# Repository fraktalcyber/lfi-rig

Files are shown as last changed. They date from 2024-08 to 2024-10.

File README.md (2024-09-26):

# Fraktal - Laser Fault Injection (LFI) rig

This project is Fraktal's take on building an affordable Laser Fault Injection rig that allows anyone to get started with performing laser fault injection attacks, previously left only for laboratories and research institutes with expensive equipment. With this breakthrough, we hope to inspire a new wave of research and development in hardware security.

The series of blog posts related to this repository can be read from our blog
[Part 1](https://blog.fraktal.fi/laser-fault-injection-for-the-masses-1860afde5a26),
[Part 2](https://medium.com/fraktal/laser-fault-injection-for-the-masses-part-2-b86a42fd28a1), 
[Part 3](https://medium.com/fraktal/laser-fault-injection-for-the-masses-part-3-86372a233db9)

## Contents of the repository

- **Decapping** - Instructions, guidance and methodologies for decapping chips
- **LFI** - Instructions, guidance and methodologies for Laser Fault Injection and how to get the best out of the rig
- **Other** - Various other things and source material we have created and come across
- **PCB** - KiCAD project, schematic and board files for the XY2-100 driver board
- **rigv2** - 2nd generation rig using off-the-shelf xTool F1 laser engraver
- **src** - Micropython script including the XY2-100 software driver and control for the laser PWM, beam pattern visualizer

## UPDATE
Rigv2 using off-the-shelf xTool F1 laser engraver. A bit more money but a lot less hassle. Read the details from [rigv2](/rigv2/README.md)

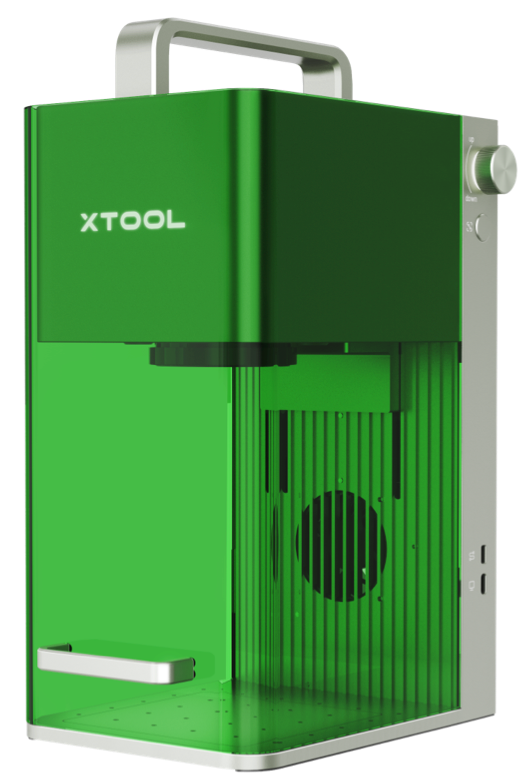
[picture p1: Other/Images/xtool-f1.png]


## Chip Decapping
**The rig is capable of decapping chips!** This capability drastically simplifies the decapping process, as you can decap and then immediately move on to glitching the chip — no need to switch between different equipment or complicated setups. Read more from [decapping](https://github.com/fraktalcyber/lfi-rig/blob/main/Decapping/README.md)

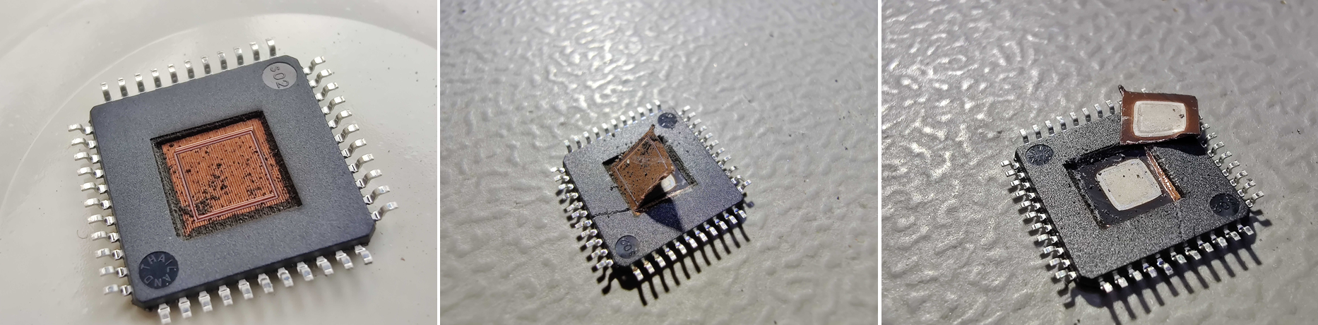
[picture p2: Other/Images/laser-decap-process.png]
Laser Decap


## WARNING

**Before attempting to build and use this rig, please be aware that the 1064nm IR laser is invisible to the eye and extremely dangerous. As the rig is running high powered lasers even a reflected beam can cause immediate severe eye damage.** 

It is imperative to wear laser safety goggles that filter out 1064nm light and to operate the rig in a secure, enclosed box. Line the box with aluminum foil or similar materials to ensure the IR light cannot penetrate. Safety should always be your top priority as any damage to your sight is likely going to be permanent. Also be aware of the potential fire hazards as a powerful IR laser will easily burn through even thin metal.

When buying goggles, get them from reputable sources that provide some certification or other documentation so you can be sure the glasses actually filter the wavelengths. [Example from Farnell](https://fi.farnell.com/imatronic/1900-08-000/laser-safety-glasses-870-1085nm/dp/2334333)

**If you decide to decap chips with the rig here are some additional warnings.**

Ensure you have adequate fume extraction as the fumes emitted from the burning epoxy, fillers and additives in the coating can be very toxic to inhale. We are performing this in a sealed enclosure with Weller fume extractor that has active carbon filter. 

Fire hazards, as you are giving laser treatment for the epoxy, even though it has flame retardants, there is still a risk of combustion. Never leave the rig without supervision when doing this and have fire extinguisher at hand just in case.

## Shopping list

This details the main components needed to build the rig. The bill of materials for the XY2-100 driver board is listed in the README.md under the PCB folder.

- **Galvanometer (Galvo scanner):** Any that uses XY2–100 protocol and has 1064nm IR coating on the mirrors will do.  These can be had from AliExpress from various sellers for around 130 €, prices seem to vary wildly between sellers and days. If it has a DB-25 connector it likely works with our driver board directly
- **1064nm F-Theta lens:** The smaller the scan area / focus length, the higher the precision. Around 50 €.
- **1064nm IR Laser light source:** Any with at least 200 mW of optical power. The more powerful laser you have the faster you can run the rig. We started with a 200mW module which we were able to haggle to around 50 € from Alibaba but eventually settled for an off-the-shelf Sculpfun IR-2, 2W IR laser module which has integrated driver and enough power to run the rig as fast as the mirrors can move. We managed to get the IR-2 module from a campaign in Alibaba for 220 €. IR-2 is also nice because it has a red alignment laser which makes it possible to see where the laser is pointing.
- **Raspberry Pi Pico:** 5 €.
- **4 channel RS-422/485 driver:** To drive X, Y, Sync and CLK channels in XY2–100 protocol. We used Analog Devices LTC487CSW, 10 € .
- **Power supply:** Capable of providing +-15V @ 2A, we initially used a multi-channel bench power supply. For the final version we used embedded Tracopower TEN60–2423N supply which is 97 € but makes it possible to have everything in a single PCB.

## Assembly and setup

After obtaining all of the required items from the shopping list (and optionally built the driver board all you have left is to assemble the thing. If you went with the Sculpfun IR-2 laser this step is pretty straight forward.

### Mounting the laser to the Galvanometer

Mount the laser to the hole in the galvanometer. You can build proper brackets or just duct tape it together like we have. Both work equally well. Whatever you do, leave things a bit loose for now so that it is possible to align the beam to the center of the hole when you power the rig on.

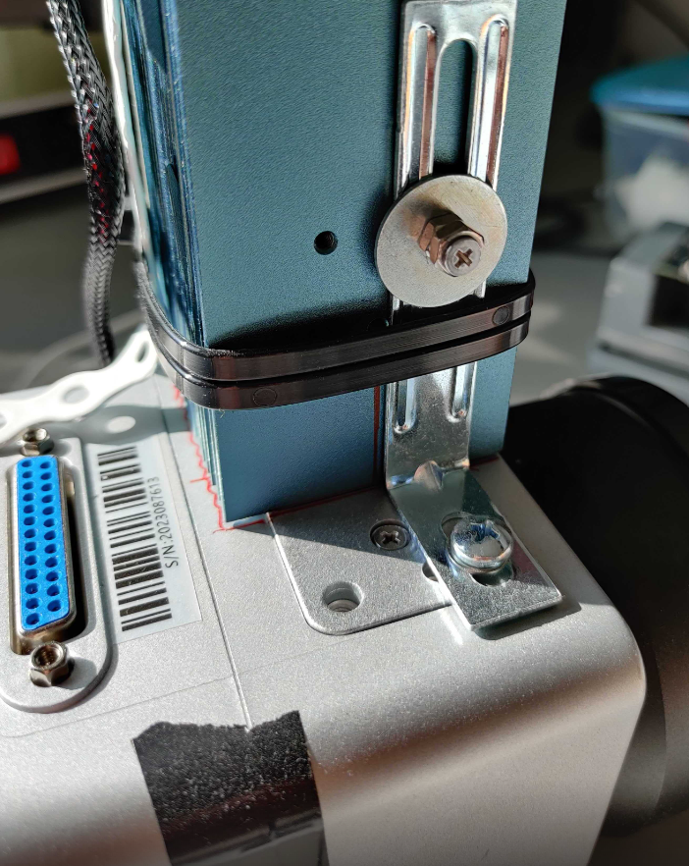
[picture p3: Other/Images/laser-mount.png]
Laser Mount


### Attaching the lens

Screw in the F-Theta lens. Before attaching the lens, make sure the mirrors and the lens are clean and don't have any dust particles or other dirt as that will be likely burnt to the mirror surface when you first time power on the laser.

### Holding the rig in place

We are holding the rig in place in our lab simply with a monitor mount that can be height adjusted and which has VESA mount that can be tilted 90 degrees. The VESA mount has two L-Brackets attached to it that hold the rig in place.

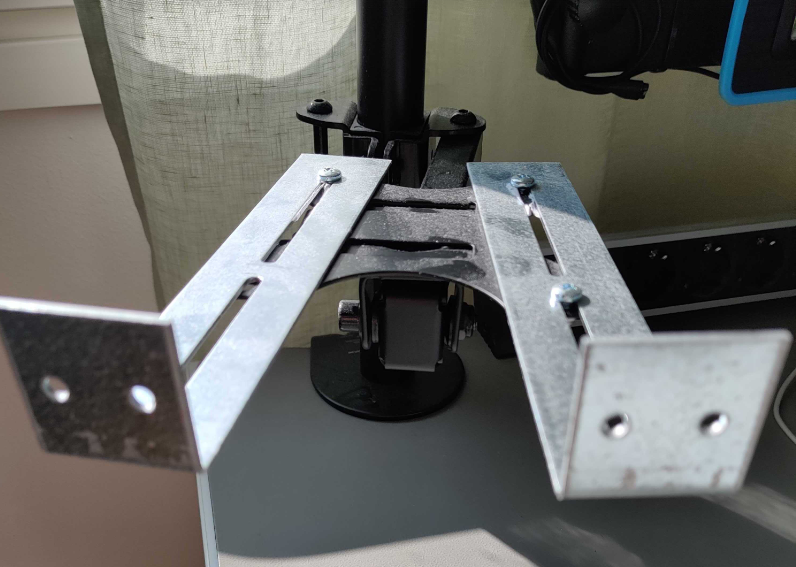
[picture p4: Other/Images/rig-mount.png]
Rig Mount


### Assembling the driver PCB

The driver PCB has very few parts and is pretty straight forward to assemble. There are only few things that should be considered.

- Although the Raspberry Pi Pico can be mounted flush on the PCB we suggest mounting a pin header to the holes and then pressing the Pico in. This has benefits, it leaves a bit more clearance under the Pico and fits even the bulkiest Micro USB cables, it allows to use the pads to mount wires and additional headers for monitoring etc. We are for example driving the target chip power often straight from the Pico as this makes wiring a bit simpler. For this we have added few extra headers for select pins.
- **DB-15 Header should be mounted to the backside of the PCB**, with the rest of the components on the frontside where the Raspberry Pi Pico is.
- The PCB BOM is listed with more detail underneath the PCB folder

### Connecting all the cables and wiring pinouts

Most of the available galvanometers seem to be using similar structure and come with DB-25 connector in the galvanometer itself. It is still worth to check that the one you are planning on buying has same or similar pinout to what we used if you are planning on running our driver board.

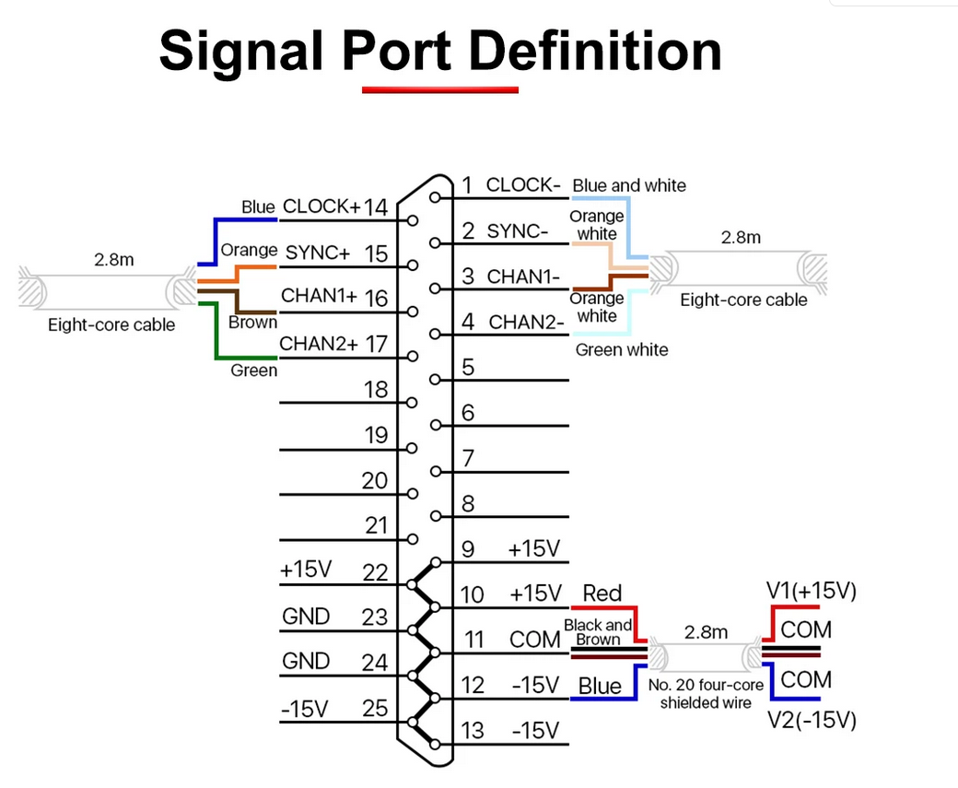
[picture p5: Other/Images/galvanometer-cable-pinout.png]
Galvo Pinout


These galvanometers come with wiring harness that has DB-25 that goes to the galvanometer with the other end having DB-15 and four loose cables. The DB-15 connector is used for the XY2-100 four channels and you can verify the pinout by beeping the cable with a multimeter in continuity mode. DB-15 should work directly with our driver and can be connected straight to the PCB.

*As we didn't want to run the rig from mains with insufficient protections, We ditched the power supply that came with the galvanometer as that connects straight to mains and doesn't offer same amount of protections as a lab power supply can provide.*

The four loose cables we had in our harness were coloured blue (-15VDC), black (GND), red (+15VDC) and yellow (Mains Earth **DO NOT CONNECT THIS UNLESS YOU KNOW WHAT YOU ARE DOING**). Blue, black and red wires can be connected to the Galvo OUT header on the driver PCB.

If you are running the Sculpfun IR-2 laser, the laser probably came with this type of connector.

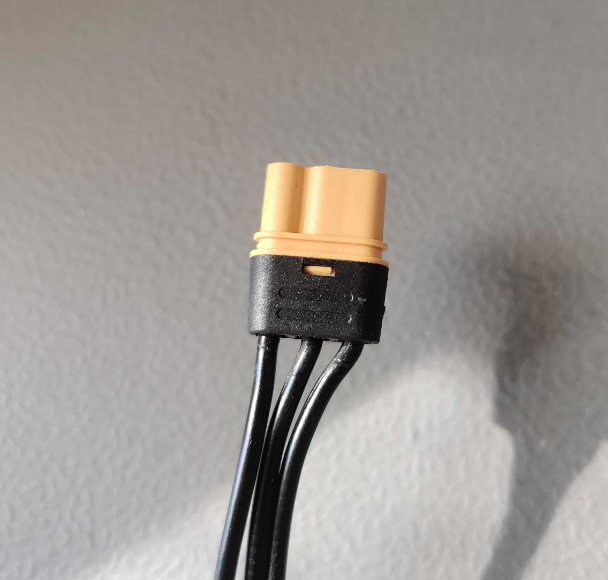
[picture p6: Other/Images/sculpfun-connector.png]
Sculpfun Pinout


The pinout for the connector is from left to right, 1kHZ PWM signal @ 3V3, GND, +24VDC

When connecting the PWM signal to the respective header on the driver PCB, it is **highly recommended to add a mechanical switch on the signal wire** this allows you to have a mechanical safety switch and prevent accidental running of the laser main beam. Only toggle the switch when everything is enclosed and you are wearing your goggles.

With everything connected it is time for test run!

### Testing the rig works and aligning the laser

With everything connected and setup the first thing you should do is to align the laser. If you went with Sculpfun IR-2, you can power the laser **with PWM signal disconnected**. This should give you a red laser spot that is the alignment beam that is firing **when the main beam is not firing**. The alignment beam spotsize is much larger than the actual IR laser spot but it can be used to align the laser horizontally and vertically to make the spot as small as possible. We haven't felt a need to do anything but an alignment visually when it looks the smallest. That has been sufficient as the rest can be compensated with software parameters.

In order to get the laser pointing through the F-Theta lens, you also need to power on the galvanometer. When giving the galvanometer -15VDC and +15VDC it centers the mirrors into zero position and makes sure that your laser spot actually goes through the lens. 

Move the laser in its mount so that it is roughly in the center of the input hole, and the laser comes through as middle of the lens as possible. Once the laser is centered, tighten all of the screws or duct tape the laser in place.

Then adjust the horizontal alignment of the whole rig by moving it up and down in the rig mount and try to get as small beam as possible.

We are running IR-2 without the collimator lens that came with the laser as we have found that it makes it easier to mount the laser flush with the galvanometer. You should try it with and without and move the laser horizontally as well to find what works best for your setup and the selected F-Theta lens. Each setup is slightly different so there are no direct guides how to get the smallest spot size on your specific setup.

After the laser is aligned and as small as possible it is time to test the mirrors move and can be controlled. To do this, **still with the PWM signal disconnect** run the findPerimeter function with parameters (x-axis start position, x-axis end position, y-axis start position, y-axis end position, time to sleep before running the perimeter) so for example

	findPerimeter(0,3500,0,3500,0)

This should draw a square with the scanning laser on whatever surface you have underneath the laser. If you can't see a uniform sized square, the mirrors don't move fluently, if you see laser points outside of the square or anything else. You need to do some debugging and figure out what is wrong.

If you on the other hand see a square, now you can use the square to align the laser rig and check that it is not tilted. We have found best to have some uniform known sized square that you use as a reference such as graph paper. Align the x and y axis in the function to get the right size and then align the rig with the graph paper on a flat surface to get the rig to be level. This is important especially if you are running the rig at full speed as slight misalignment here will mean different laser power hitting different parts of the chip. Ideally you'd want to have as uniform and flat plane as possible.

If everything works and you have everything setup now its time to try on some actual samples.

## Running the rig in fault injection mode

Provided that you managed to get everything working and setup, and have a decapped IC using our method or any other method. It is time to run the rig in fault injection mode.

You should start with mounting the sample underneath the rig as center as possible and adjusting the perimeter size using the findPerimeter function. When adjusting the perimeter, it is a good idea to go slightly over the actual die, that way you will not be missing the edges of the die which may or may not have something that causes faults. Having the sample as center as possible makes the lens work the best and keeps the spot as uniform as possible.

With the perimeter setup and parameters found it is time to put the rig inside a box, enclosure and shield your eyes with the glasses. What we have done is to add a webcam or some camera inside the box to be able to see what is happening. With most webcams it is also possible to see a faint violet tint when the IR laser main beam is firing, similar to what you can see when you view your TV remote using your phone camera.

The main function to be used for scanning the die to produce faults is scanChip.

	scanChip(0,3500,0,3500,40,True)
	
The function takes as parameters the chip perimeter and the "hop" or how much the mirrors are to be moved with a single drive cycle, the last value is True/False if the laser should be firing or not. For a test run we suggest running the scanChip with laser turned off and only the alignment beam lit, this allows you to see the scanning is working properly and that you are scanning the entire die area.

If the dry run works it is time to run with the main beam. If using the IR-2 laser a suggested starting point value for power is 8000 for the duty cycle. This has in our experiments been a nice baseline as (depending on the hopsize, thus the mirror speed) it has been enough power to cause faults to appear in most of the chips we have tried.

It is always best to start with a chip where you have full control, via a debugger or running a software loop that you know what it is doing.. We did initial tests with having a same chip as our target chip was, and run a sample firmware that runs in while true loop and just prints incrementing number into UART. Then we adjusted first the power level to something where we start seeing faults happen. Then we played around with the hop parameter and adjusting the power so that we can run the rig as fast as possible while still producing same or similar faults as initially observed.

Now the rig and parameter should be setup for trying the rig with an actual target chip and to try and for example bypass code readout protections or secure boot verifications. 

**ENJOY!**

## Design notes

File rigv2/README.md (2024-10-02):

# Off-the-shelf Laser Fault Injection rig, lfi-rig v2
Don't want to start toying with soldering or getting PCBs manufactured, but have a bit more money to spend. For 1449eur (VAT incl) you can buy a very capable LFI rig that can be used to both decap chips and perform laser fault injection without any hardware modifications. 

**Some warnings:** You will be talking to the device directly, this may result in permanently breaking the device. This may happen by sending incorrect commands or badly formatted G-Code files. As you are directly controlling the device and its laser power, the same precautions apply as with our rig v1, namely cover your eyes and vent fumes. Thoroughly read this write-up, as well as, the information relating to the G-Code before attempting this.

xTool F1, image (c) xTool

## xTool F1
If the xTool marketing is to trust this device is Fastest Portable Laser Engraver with IR + Diode Laser. Or maybe to rephrase Fastest Portable Laser Fault Injection and Decapping rig. For a slight bit more money, this offers many improvements over our previously introduced DIY budget rig. 

- No hardware modifications necessary that would void warranty. Yes, lfi rig with 24 month warranty :D 
- Electronically adjustable, auto calibrating Z-axis focus
- 2 lasers, same spec 2W (1064nm) IR laser as in our rig v1 + a 10W (455nm) blue laser
- Control using G-Code files that can be easily shared
- Even faster and more precise newer tech galvanometer
- Enclosed design with outlet that can be attached to a fume extractor
- Laser safe (at least supposedly) enclosure

We pitted the xTool F1 against our rig v1 and here are the main differences:

**lfi-rig v1 vs xTool F1**
- **Price:** 500eur vs 1449eur
- **Laser Decapping accuracy with IR laser:** Very similar provided you have the focus nailed for v1. xTool makes the focus setting and repeatability much better.
- **Laser fault injection accuracy:** Very similar provided you have the focus nailed for v1. Again, xTool makes this much easier to get right.
- **Speed:** xTool is much faster. Hard to give absolute figures but 10x is probably not far off.
- **Ease of use and setup:** xTool requires absolutely nothing special, just install the drivers and you are good to go. You can use anything from curl to our Python scripts *(WIP)* to use it. You are up and running in less than 5 minutes
- **HW hacking scene credibility points:** v1 no questions asked. xTool is like turning up into a tuning car meetup in a grey VW Golf.

## The setup
xTool F1 has few ways of connecting to it, you can use the USB-C port on the side of the device, or Wi-Fi. In either case the device can be reached via HTTP API on port 8080. If using USB-C you will need to install the xTool USB-Ethernet driver (generic CH340 drivers might work too), after which the device is presented as USB-Ethernet interface on the host computer. xTool [support website](https://support.xtool.com/product/2) has all the necessary details. It is good idea to do a smoke test, pun intended, with the official software just to verify the device works as intended. As the setup process has a fair amount of parameters it is suggested that you do perform the initial machine setup using the XCS desktop or mobile application. This also verifies the device is running the most recent firmware version.

## Talking to xTool F1
To control the device there are four main commands you will need. Before you get started, verify the device responds. The easiest way to do this is via browser. Over plain HTTP, access this URL: ip:8080/system?action=version_v2 This should give you a JSON-formatted output showing various machine related information. If this works, you are good for the next steps.

**The main commands**
- **Focus control POST-request:** *ip:8080/focus/control* - This adjust the Z-axis and the focus point of the laser
- **Framing POST-request:** *ip:8080/processing/upload?gcodeType=frame&fileType=txt&autoStart=1&loopPrint=1* - This will run the device in framing mode scanning whatever G-Code you give it. This will only end with the Stop command
- **Lasering POST-request:** *ip:8080/processing/upload?gcodeType=processing&fileType=txt&taskId=1234* - This will run the device in lasering mode
- **Stop POST-request:** *ip:8080/processing/stop* - This command will stop whatever the device is doing, whether framing or lasering

## Autohoming or auto calibration
Autohoming of the device can be perfomed by sending a following HTTP post message:

```
URL: POST ip:8080/focus/control
Payload: {"action":"goTo", "autoHome":1, "z":23.5, "stopFirst":1, "F":300}
```

What this does is, it sets the Z-axis zero point to the surface of the bottom plate of the device. Z equals 23.5mm which is the height at which the base plate is sitting from the desk surface.

It is a good idea to always run this first to ensure Z-axis accuracy when performing the actual lasering. If using the baseplate the Z-height should be calculated 23.5mm + the height required by your chip or PCB.

## Z-axis focus
With the Z-axis zero point set to the bottom plate any further Z-axis adjustments can be made in reference to the zero point (23.5mm). The same command can be used to adjust the Z-axis focus. For example setting the focus point to 1.23mm would result in z-parameter to be (23.5mm+1.23mm = 24.73mm)

```
URL: POST ip:8080/focus/control
Payload: {"action":"goTo", "autoHome":1, "z":24.73, "stopFirst":1, "F":300}
```

## Framing Mode- This can be used for LFI
Framing is by default using the blue laser on the device with just lower power to show the outline of the shape you want. Now, as we are sending raw G-Code to the device it is possible to accidentally set the laser power high enough to actually start cutting/engraving whatever you have underneath. **So make sure the power is set to max 0.064 (so 6.4%). If you just want to do framing.** This is the default and safe setting used by xTools own XCS studio software.

**As we have complete control over the G-Code, this functionality can be used to run the device in a looping laser fault injection mode.** To achieve this change the laser to IR (using G-Code G22) and set the power and feedrate to your liking. The process will continue indefinitely until you run the stop command.

```
URL: POST ip:8080/processing/upload?gcodeType=frame&fileType=txt&autoStart=1&loopPrint=1
Payload: Text format G-Code file with some additions
```

Notes on the URL parameters. If you want the framing to start only when you press the rotary button on the side of the device **(this is a good idea if you use the IR laser)**, leave the autoStart-parameter off. loopPrint-parameter is controlling whether the device will keep on looping the same G-Code file or just run it once. 

**Important notes for the G-Code**:
xTool seems to use slightly varied [Marlin G-Code](https://marlinfw.org/meta/gcode/) for controlling the device. The G-Code files in framing mode that are sent to the device should be structured as follows. More details regarding the xTool G-Code structure can be found below and examples G-Code files can be found under the examples folder.

```
G0 F180000    - Set feedrate laser off to 3000mm/s (max)
M4 S0         - Laser power on, power level to 0
G1 F180000    - Set feedrate laser on to 3000mm/s (max)
M114 S1       - ?? Get current position or some kind of framing related setup parameter
G21           - Select which laser to use, G21 = blue, G22 = IR
G90           - Set absolute positioning

-- add here your actual G-Code coordinates --

G90           - Set absolute positioning
G0 S0         - Laser power to 0 ??
G0 F180000    - Set feedrate laser off to 3000mm/s (max)
G1 F180000    - Set feedrate laser on to 3000mm/s (max)
M6 P1         - Stop lasering process, clean-up and power off the galvo and lasers
```

## Laser Processing Mode - This can be used for laser decapping
This works largely in the same manner as the framing and uses the same HTTP endpoint. It just omits the autoStart and loopPrint parameters to add some safety in that you will need to trigger the process using the button on the side of the device and it only runs the sent G-Code once. TaskId just seems to be random string of letters and numbers that the device can use to keep track of the task and will use it when returning information on the progress.

```
URL: POST ip:8080/processing/upload?gcodeType=processing&fileType=txt&taskId=xxxxx 
Payload: Text format G-Code file with some additions
```

**Notes on the G-Code for this**
```
G90           - Set absolute positioning
G0 F3000      - Set feedrate laser off to 50mm/s
G0 F180000    - Set feedrate laser off to 3000mm/s (max)
M4 S0         - Laser power on, power level to 0
G1 F180000    - Set feedrate laser on to 3000mm/s (max)
G0 X0 Y0      - Set galvanometer to 0,0 point
G21 (or G22)  - Select which laser to use, G21 = blue, G22 = IR
G90           - Set absolute positioning

-- add here your actual G-Code coordinates --

G90           - Set absolute positioning
G0 S0         - Laser power to 0 ??
G0 F180000    - Set feedrate laser off to 3000mm/s (max)
G1 F180000    - Set feedrate laser on to 3000mm/s (max)
M6 P1         - Stop lasering process, clean-up and power off the galvo and lasers
```

# xTool F1 G-Code

## High-level summary of the G-Code structure.

```
G0X55.500Y55.500
G1X59.500Y55.500S64F720000
G1X59.500Y59.500
G1X55.500Y59.500
G1X55.500Y55.500
```

The main G-commands the device uses are **G0** - galvo head movement with laser off and **G1** - galvo head movement with laser on. G0 and G1 move commands take the co-ordinates in millimeters with the 0,0 point being the top left corner of the stage. The G-Code should be done in a way that it is as center of the stage as possible or around coordinates X50.00Y50.00. This means the least deflection of the laser through the optical path and consequently more power and less optical distortions.

The first G1 command should append to the command additional parameters, namely **S** and **F**. Where S controls the laser power and F is the feedrate or the movement speed.

The laser power is given in percentages without decimal point, with the last digit being the decimal. 1000 being equal to 100% and numbers such as 64 being 6.4%

## G-Code file header

**Header in "processing"-mode**
```
G90           - Set absolute positioning
G0 F3000      - Set feedrate laser off to 50mm/s
G0 F180000    - Set feedrate laser off to 3000mm/s (max)
M4 S0         - Laser power on, power level to 0
G1 F180000    - Set feedrate laser on to 3000mm/s (max)
G0 X0 Y0      - Set galvanometer to 0,0 point
G21 (or G22)  - Select which laser to use, G21 = blue, G22 = IR
G90           - Set absolute positioning
```

**Header in "framing"-mode**
```
G0 F180000    - Set feedrate laser off to 3000mm/s (max)
M4 S0         - Laser power on, power level to 0
G1 F180000    - Set feedrate laser on to 3000mm/s (max)
M114 S1       - ?? Get current position or some kind of framing related setup parameter
G21           - Select which laser to use, G21 = blue, G22 = IR
G90           - Set absolute positioning
```

The G-Code files sent to the device always begin with the following header. These are used to setup the basic parameters for the galvanometer and lasers. Until there is better information, it is better to append this **as it is** to any G-Code files sent to the device. This is to ensure the device works as intended.

## G-Code file end

```
G90           - Set absolute positioning
G0 S0         - Laser power to 0 ??
G0 F180000    - Set feedrate laser off to 3000mm/s (max)
G1 F180000    - Set feedrate laser on to 3000mm/s (max)
M6 P1         - Stop lasering process, clean-up and power off the galvo and lasers
```

The G-Code files sent to the device always end with the following G-Code commands. Until there is better information, it is better to append this **as it is** to any G-Code files sent to the device. This is to ensure the device works as intended.

## xTool F1 G-Code commands

### G0 - Linear move, laser off
**Command structure - G0Xnn.nnnYnn.nnnSnnnnFnnnnn**

- X, X-coordinate in millimeters
- Y, Y-coordinate in millimeters
- S, laser power decimal number with single decimal, without decimal separator e.g 64 = 6.4 or 800 = 80.0
- F, Feedrate (movement speed). Calculated with the formula (speed in mm/s)*60 = feedrate e.g. 160mm/s => 160mm/s*60 = 9600

**Special cases**

- G0 F180000 - ?? Setting of the maximum feedrate? As this is only used in the init section
- G0 X0 Y0 - Position the galvanometer to its zero point

### G1 - Linear move, laser on
**Command structure - G0Xnn.nnnYnn.nnnSnnnnFnnnnn**

- X, X-coordinate in millimeters
- Y, Y-coordinate in millimeters
- S, laser power decimal number with single decimal, without decimal separator e.g 64 = 6.4 or 800 = 80.0
- F, Feedrate (movement speed). Calculated with the formula (speed in mm/s)*60 = feedrate e.g. 160mm/s => 160mm/s*60 = 9600

**Important Notes**
The first G1 command should always be used to set the feedrate. This can be done either by issuing a separate G1 command (see below). Or by setting it as part of the first G1 command such as G1X55.00Y55.00S800F6000 (Move the galvanometer head to point X55 Y55, turn the power to 80% and set the feedrate to 100mm/s.

**Special cases**

- G1FnnnnnSnnnn - Set the feedrate for the laser on move commands, S-parameter should be set to 0 in this command

### G21 - Select Blue (455nm) laser
**Command structure - G21**

No parameters

### G22 - Select IR (1064nm) laser
**Command structure - G22**

No parameters

### G90 - Set absolute positioning
**Comand structure - G90**

No parameters

### M4 - Laser power on
**Command structure - M4 Snnnn**

- S, laser power decimal number with single decimal, without decimal separator e.g 64 = 6.4 or 800 = 80.0. **Suggested setting here 0**

### M6 - Stop the lasering process, power off everything
**Command structure - M6 P1**

- P, ?? Not sure what this means better to just send it as P1 until there is better understanding

### M114 - Some framing related setup command
**Command structure - M114 S1**

- S, ?? No clear understanding what this means

# Suggestions/ideas for sharing LFI and decap files
The use of G-Code makes it possible to easily share chip specific LFI and decap files. Here are some ideas how to share these files. **What we are doing is splitting the setup into three separate G-Code files. Alignment framing file, decap file and LFI file.** As it is possible to add all the necessary parameters such as speed(feedrate) and power, along with the coordinates to these files, the only additional setup left for the person using these files is to setup the correct Z-height for the laser. Which is dependant on the breakout board and other variables.

**Alignment framing file**

To ensure the alignment of the chip underneath the laser, it is suggested to start with an alignment framing file (using blue laser, repeating indefinitely). This should be a file that has just the outline of the chip so that it can be accurately be aligned under the laser.

**Decap file**

Provided the alignement is good and the chip can be placed in the correct location the next file to share is to perform the decapping on the chip. This should make it easy to repeat the decapping process successfully for the chip in question.

**LFI file**

The last part, the LFI (laser fault injection) file is another framing file but using IR laser. This file should have the area where the possible fault injection should be performed.

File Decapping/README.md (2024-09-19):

# Introduction to chip packaging and decapping

Integrated circuits (ICs) are delicate silicon-based structures that require protection from environmental factors like moisture, dust, and mechanical stress. Without packaging, the silicon dies would be exposed and highly vulnerable to damage. Early on, before advanced packaging became common, many systems used Chip-on-Board (COB) techniques where the silicon die was bonded directly onto the PCB and then covered with a protective epoxy blob.

These “COB blobs” offered minimal protection and were often used in low-cost devices where size and durability weren’t critical.

To ensure the durability and longevity of the chips, the concept of IC packaging evolved, providing mechanical protection, heat dissipation, and easier handling during assembly. The IC package plays a crucial role in connecting the internal chip to the external environment, usually through metal leads or solder balls that link the chip to a printed circuit board (PCB).

The structure of most modern IC packages is relatively straightforward:

- **Die:** The core silicon IC where all the operations happen.
- **Die Attach/Die Pad:** A platform that holds the die in place.
- **Wire Bonds or Flip-Chip Connections:** Connecting the die to external leads or pads.
- **Lead frame or interconnect:** Connecting the wire bonds to the leads or solder balls that attach to the PCB
- **Encapsulant (Epoxy):** The protective material covering the die and wires, which is typically made of tough epoxy resin often mixed with fillers like glass beads to enhance durability.

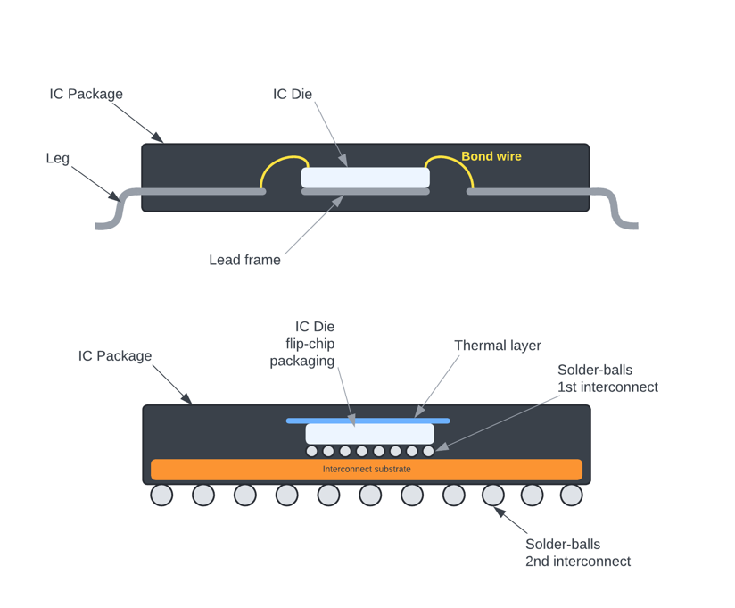
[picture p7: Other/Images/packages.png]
Example of IC packages


# Leaded Packages

Leaded packages, such as Dual In-Line Packages (DIP) and Small Outline Integrated Circuits (SOIC), are among the oldest and most recognizable formats. These packages have metal leads extending out from the sides, which are soldered to a PCB. They were widely used in early electronics due to their ease of handling and soldering, but their larger size and bulk made them less suitable for modern, compact electronics.

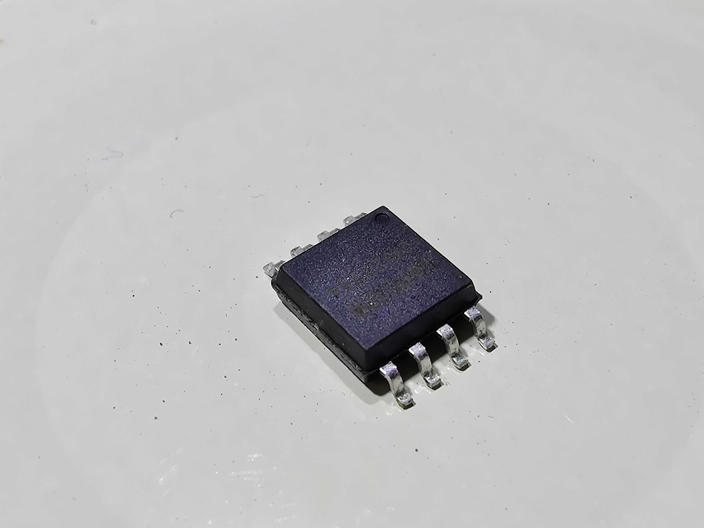
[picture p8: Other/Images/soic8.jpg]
SOIC-8 package


As electronics evolved, the leaded packages got more crowded and smaller, resulting in the introduction of Small-outline package (SOP), a miniaturized version of SOIC and Quad-flat package (QFP) which saw leads poking out from all of the four sides of the package.

In leaded packages, the die is encapsulated in epoxy with the leads (usually made of copper or tin) extending out for easy connection to a circuit board. However, these packages take up significant space on the PCB, which is a major drawback as devices become smaller and more densely packed with components. Consequently, leaded packages are becoming less common, particularly in high-density applications.

## Quad Flat No-lead (QFN) and Similar Packages

The Quad Flat No-lead (QFN) package is one of the most widely used formats today, thanks to its compact form factor and efficient heat dissipation. QFNs are leadless packages where the chip’s contacts are exposed on the underside of the package with much smaller footprint than traditional leaded packages.

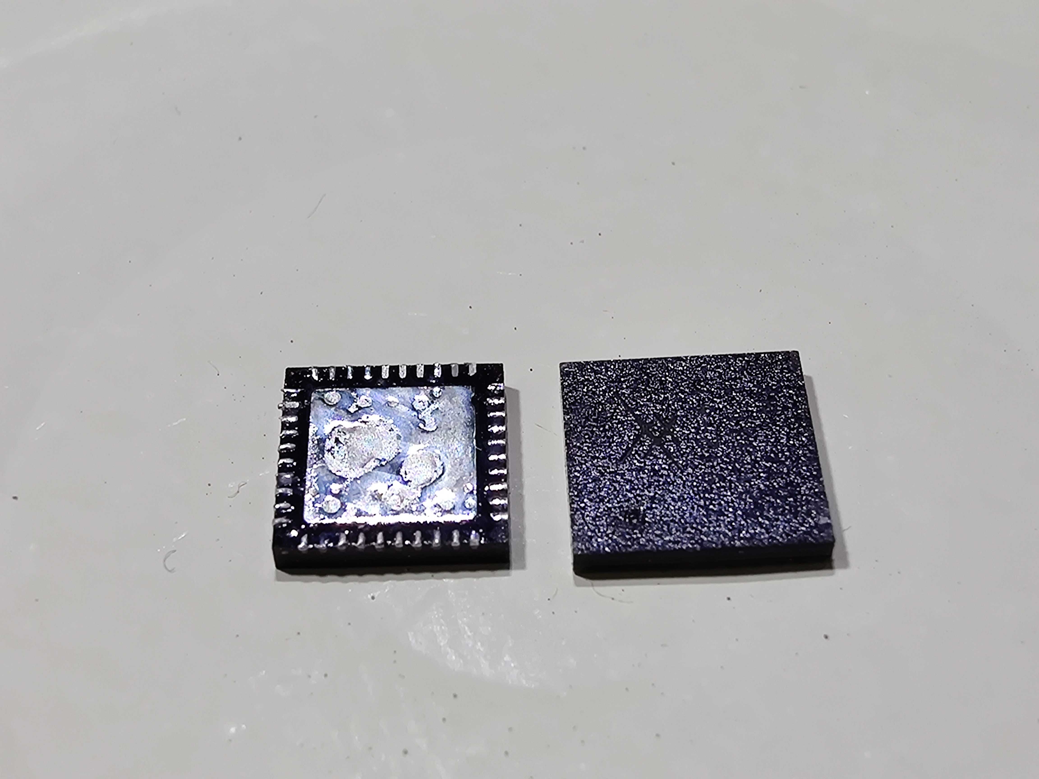
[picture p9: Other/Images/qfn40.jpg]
QFN-40 package


The structure of QFNs still includes the die mounted onto a lead frame, but the leads are encapsulated underneath, making the package thinner and more space-efficient. The use of QFNs and similar leadless packages has become especially popular in mobile devices, wearables, and other applications where space is at a premium.

##Ball Grid Array (BGA)

The Ball Grid Array (BGA) package represents a further evolution in packaging. Instead of leads or pads, BGAs use a matrix of solder balls on the underside of the package to connect to the PCB. This design offers several advantages:

- Smaller footprint: By placing the connections under the chip, BGAs save significant space on the PCB.
- Improved thermal performance: The package design facilitates better heat dissipation.
- Higher pin count: BGAs allow for more connections without increasing the package size, making them ideal for high-performance chips.

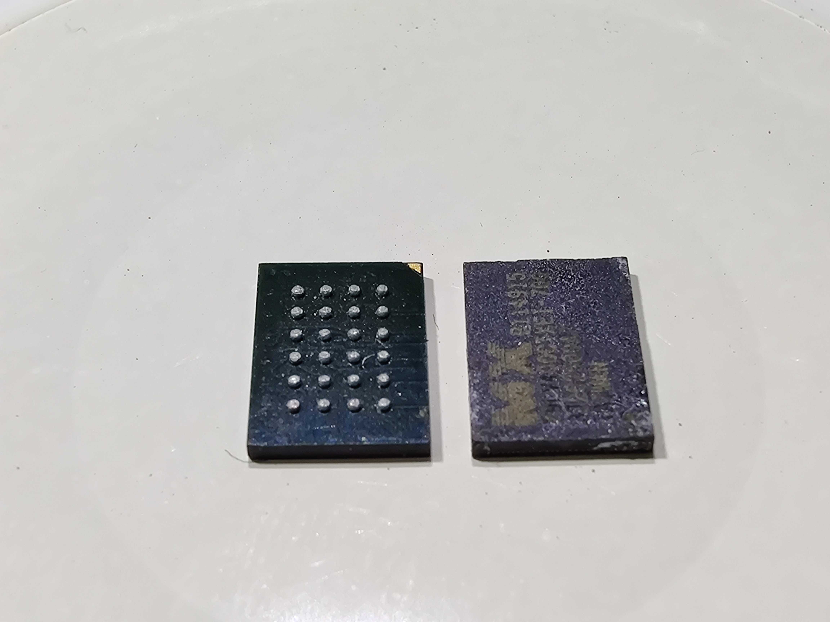
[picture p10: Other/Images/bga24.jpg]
BGA-24 package


BGAs are commonly used in microprocessors, RAM, GPUs, and other high-density chips. The array of solder balls underneath and their smaller size makes them more challenging to handle and solder manually, often requiring specialized equipment for rework.

## Chip-Scale Packages (CSP) and Wafer-Level Chip-Scale Packages (WLCSP)

As the demand for smaller, more efficient devices grows, packaging technology has reached a point where the package itself is barely larger than the chip. Chip-Scale Packages (CSP) are defined as packages where the package size is no more than 20% larger than the die itself.

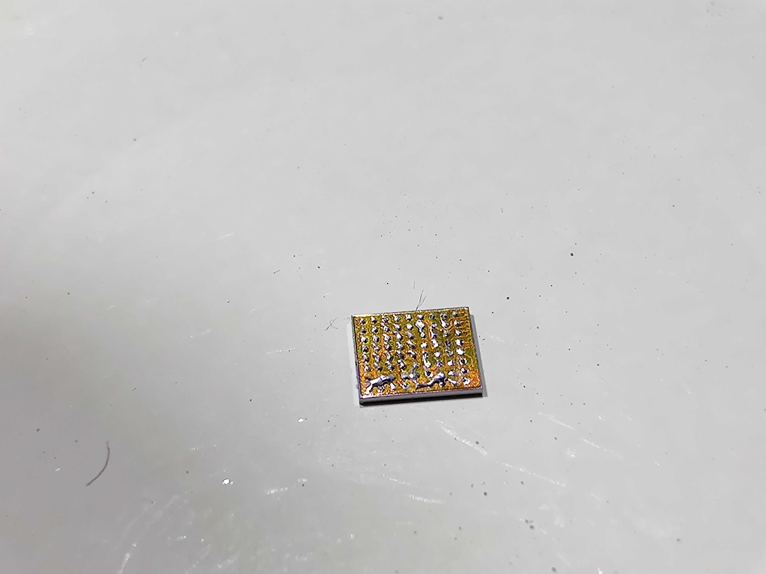
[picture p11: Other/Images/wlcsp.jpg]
WLCSP package


The most recent development of CSP is the Wafer-Level Chip-Scale Package (WLCSP). In WLCSP, the die is packaged directly at the wafer level before being cut and placed into devices. This reduces the packaging overhead to almost nothing, making WLCSP the smallest and most space-efficient package available. WLCSPs are widely used in mobile phones, sensors, and other ultra-compact electronics where size is critical.

One interesting challenge with WLCSPs, especially in the context of Laser Fault Injection (LFI), is the thinness of the molding compound. In some cases, the encapsulant is so thin that it might be sensitive to the laser even without decapping. This opens up possibilities for direct fault injection without the need to physically remove the package material, allowing for quicker and more efficient attacks on WLCSP chips compared to older, more robust packages.

# Packaging Composition

While there are various materials used in IC packaging, epoxy-based packages are by far the most common and notoriously challenging to deal with when attempting decapping. This is why, for the purpose of this post, we’ll focus solely on epoxy-based packaging. Understanding the composition of the epoxy and its interaction with other materials within the package is crucial when developing a decapping strategy, particularly if the goal is to keep the chip functional after decapping.

## What is Epoxy Packaging?

Epoxy packaging is the protective (almost always black) material to encapsulate the die, providing mechanical support, environmental protection, and electrical insulation. The epoxy-based packaging materials are extremely durable and heat resistant, making them ideal for long-term use in various applications. However, this durability is in our case a double-edged sword— while it protects the chip from external damage, it also makes decapping quite difficult.

Epoxy-based packaging is typically composed of the following elements:

**Epoxy Resin**
The main component of the package, the epoxy resin, serves as the binding agent that holds everything together. It forms the matrix in which other elements, such as fillers, are dispersed. Epoxy is highly resistant to chemicals, mechanical stress, and heat, which makes it difficult to remove.

**Fillers (e.g., Glass Beads, Silica)**
Fillers are added to improve the mechanical strength and thermal properties of the package. In most epoxy-based IC packages, silica or glass beads are commonly used as fillers. These materials not only enhance the durability of the package but also make it more resistant to thermal expansion, ensuring that the package doesn’t crack or deform under high temperatures. These fillers are incredibly hard, which complicates mechanical decapping processes like milling or grinding. They will cause excessive wear on milling tools.

**Molding Compounds (Additives and Modifiers)**
Epoxy-based packaging often contains additional modifiers and additives to tailor the mechanical properties of the encapsulant. These can include flame retardants, carbon black, plasticizers, and other materials that modify the properties of the package to suit the need. These compounds can for example increase the resistance of the package to acids and solvents, which is why chemical decapping techniques can be ineffective or slow.

## Challenges with Epoxy-Based Packages

The combination of tough epoxy resin and hard fillers like glass beads presents several challenges when attempting to decap a chip.

If too much force is applied during mechanical decapping, there’s a risk of damaging the delicate die underneath.

Epoxy resins are designed to withstand significant heat without deforming. This makes thermal decapping methods less effective, as the heat required to melt or soften the epoxy might exceed the tolerance of the IC itself, potentially destroying the chip.

The additives and modifiers used in the epoxy can make it resistant to chemical decapping methods (acids and solvents). While chemicals like nitric acid or sulfuric acid can dissolve the epoxy over time, the process is slow and dangerous, requiring strict control of the chemicals used.

The distribution of fillers within the epoxy can be non-uniform. In some areas, the concentration of glass beads or silica may be higher, which can lead to unpredictable results when mechanically or chemically decapping. Even when using a laser, high concentrations of filler material can cause uneven burns or refraction of the laser beam.

# Decapping Methods

Several methods exist for decapping epoxy-based packages, each with its own set of advantages, disadvantages, and risks. In this chapter, we’ll explore the most common techniques — chemical, mechanical, thermal, and laser decapping — and discuss where they are most applicable, as well as the likelihood of preserving chip functionality after the process.

## Chemical Decapping (Acids and Solvents)

Chemical decapping involves using acids or solvents to dissolve the epoxy encapsulant surrounding the die. This method has been used for decades, primarily due to its effectiveness in attacking the epoxy without needing direct mechanical intervention. The process typically uses nitric acid, sulfuric acid, or a combination of both to break down the packaging material.

The process itself is straightforward: the chip is submerged in acid, which eats away at the epoxy layer over time. Nitric acid dissolves the organic components of the epoxy, while sulfuric acid can assist by burning off any remaining residues. This method is highly effective for most packages, especially those that do not incorporate filler materials designed to enhance chemical resistance.

The main advantage of chemical decapping is that it requires minimal physical contact with the chip. Because the process is entirely chemical, there’s no risk of damaging the chip through mechanical means like grinding or cutting. It’s also relatively inexpensive compared to some of the other methods. **However, chemical decapping presents significant challenges. Handling strong acids like nitric or sulfuric acid is hazardous and requires specialized equipment and strict safety protocols. The fumes are toxic, and there is always the risk of over-exposing the chip to the acid, leading to irreparable damage. Furthermore, depending on the legislation it might not even be legal to own some these chemicals.**

Prolonged exposure to acids can also result in surface damage to the silicon die and leaving the chip in the acids for too long will dissolve the bond wires or leadframe, which will render the chip non-functional.

In summary, while chemical decapping can be effective for certain types of chips, it poses significant risks to the overall integrity of the chip. The likelihood of leaving the chip functional after the process is moderate at best (unless you are John McMaster or Travis Goodspeed).

## Mechanical Decapping

Mechanical decapping, as the name implies, involves physically removing the encapsulant by milling, grinding, or cutting it away. This method is good because it doesn’t require the dangerous chemicals associated with acid decapping, and it offers more direct control over the process. Mechanical decapping can be performed using cheap tools such as a Dremel rotary tool or a CNC mill (if you have access to one). Both tools allow precise material removal by grinding away the epoxy layer bit by bit.

This methodology is presented on the index page of this repository.

One of the main advantages of mechanical decapping is that it can be performed with relatively simple equipment, making it an attractive option for hobbyists or researchers who lack access to specialized tools or chemicals. Additionally, the risk of chemical damage to the die is eliminated since the process relies solely on physical force.

There are several drawbacks, the process is slow and labor-intensive, particularly when trying to avoid damaging the die. More importantly, there’s a significant risk of accidentally applying too much force or grinding too deeply, which could ruin the chip and make it unusable.

It is possible repeatedly to succeed with mechanical decapping with some caution and precision, but the margin for error is quite small.

## Thermal Decapping

Thermal decapping is less common than chemical or mechanical methods but can be used in certain circumstances where the package material is thermally sensitive. The process involves applying heat to the package to soften or melt the epoxy, allowing the encapsulant to be peeled away or softened for easier removal. This method can be applied using a heat gun, hot plate, or other thermal sources.

The primary advantage of thermal decapping is that it avoids direct chemical exposure or mechanical abrasion, both of which carry risks of damaging the die.

However, this method is not widely used due to its limitations. Most modern epoxy materials are formulated to be heat resistant, meaning that applying enough heat to soften the encapsulant would also destroy the silicon die or degrade the chip’s functionality. Heat can also cause warping or delamination of the package, making it difficult to achieve clean results. In short, thermal decapping has limited use in practical applications and offers a very low likelihood of leaving the chip functional after the process.

## Laser Decapping

Laser decapping is as the name suggest, using a laser beam to vaporize or ablate the encapsulant material. This method offers several advantages over chemical, mechanical, and thermal decapping techniques, primarily due to its precision and non-contact nature. With a properly tuned laser, the encapsulant can be removed layer by layer, allowing for a highly controlled decap process.

A laser with sufficient power can vaporize the epoxy and the glass beads without damaging the die. The laser beam and its power can be very precisely controlled, making it possible to decap the chip quickly without compromising its functionality. One of the most significant benefits of laser decapping is its speed. While chemical or mechanical decapping can take tens of minutes or even days, laser decapping can be completed in a matter of seconds.

The laser power and pulse duration must be carefully adjusted to avoid overheating the die or causing unwanted damage. While the process is more forgiving than mechanical methods, incorrect laser settings can still result in damage to the die or surrounding components.

Based on our testing, laser decapping offers the highest likelihood of leaving the chip functional after the process. The precision, speed, and non-contact nature of laser decapping make it the preferred choice for modern IC packages, especially when working with high-value or complex chips.

# Laser Decapping Using Our Low-cost LFI Rig

One of the most groundbreaking features of our low-cost Laser Fault Injection (LFI) rig is its dual functionality. The same rig that you use for LFI attacks can also be used for laser decapping, making it an incredibly versatile tool. This capability drastically simplifies the decapping process, as you can decap and then immediately move on to glitching the chip — no need to switch between different equipment or complicated setups. By using our rig, you save time, space, and the hassle of working with multiple devices.

Once the chip is secured, the rig’s 2W infrared laser can be used to quickly and effectively remove the epoxy encapsulant. In our experiments, we’ve found that it takes just three to six quick laser passes of about three seconds each to completely eat away the epoxy and expose the die pad. Once the die pad is revealed, it easily lifts off, giving you clean access to the die.

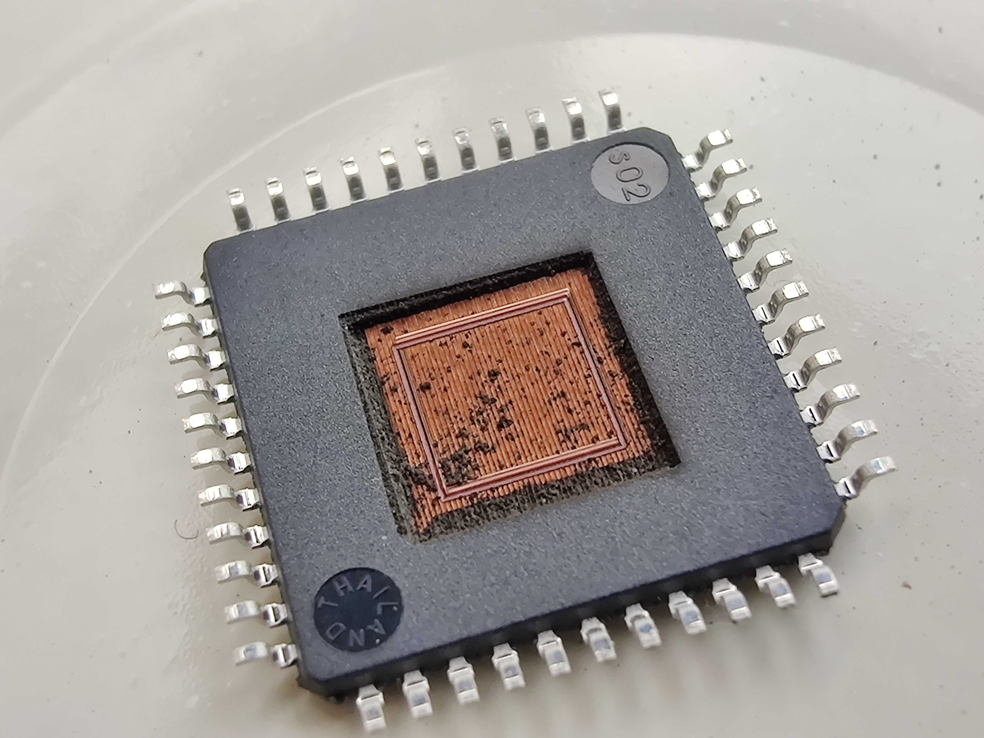
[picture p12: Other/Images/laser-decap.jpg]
Laser decapped chip


What sets this process apart is its speed and reliability. From start to finish, the entire decapping procedure takes less than a minute, with a repeatable success rate of close to 100%. This level of integration and efficiency makes our LFI rig one of the most capable tools available for both decapping and glitching, bringing high-end lab functionality into a cost-effective, compact setup.

We will start to collect and publish rig parameters and various notes under the decapping folder such as die pad location and size for each of the chips we have put underneath the rig. This should make it easier to repeat the process in the future when you want to attempt LFI for specific chip.

**IMPORTANT NOTE:** Before you try this ensure you have adequate fume extraction as the fumes emitted from the burning epoxy, fillers and additives in the coating can be very toxic to inhale. We are performing this in a sealed enclosure with Weller fume extractor that has active carbon filter.

**IMPORTANT NOTE2:** Fire hazards, as you are giving laser treatment for the epoxy, even though it has flame retardants, there is still a risk of combustion. Never leave the rig without supervision when doing this and have fire extinguisher at hand just in case.

# Step-by-step Guide

The first step in the process is that you need to acquire a few of the same chips you are working with. The reason for this is that before decapping you will need to know the structure of the chip. The most important thing to know is where the die pad is and what is its shape and size. This allows you to tune the decapping area for the laser to be just the right size and limit any possible damage.

## Research and Sacrificial Chip
Use either the laser or mechanical decapping to remove the epoxy from the entire bottom (or top if you are dealing with flip-chip BGA) of the chip until you get to the die pad. This should be done little by little to take note of anything that comes across in the layers. Once you hit the die pad, measure the size of it and see how it is attached to the leadframe. Sometimes you might have to go a bit deeper on the corners to fully reveal the mounting points. Take a careful note of the amount of passes you will have to do with the laser to get to this point.

## Trying On a Fresh Chip
Now that you know the die pad location, size and mounting style, you also know the amount of passes it is required to be done by the laser to get to the die pad, it is time to try it on a fresh chip. Perform the laser decap on a fresh chip using the settings collected from the previous step and adjust if necessary.

## Peel off the Die Pad
After the laser treatment the die pad should be visible and should in most cases peel of very easily with a sharp knife from one of the sides. Make sure you cut any mounting points before trying to peel the die pad off. The heat generated by the laser in most cases weakens the bond the epoxy has with the die pad making it really easy to peel off.

Decapped chip with die pad removed

This is the only part where there is a risk of damaging something, if the die pad doesn’t peel of easily, use the laser to get a bit more material off around the sides of the die pad. Although Star Wars tells you to “use the force”, this is not the right place for it. The less you use physical force, the less risk of damage.

## Cleaning and Testing
Clean the exposed die using isopropanol alcohol (IPA) to get the thermal adhesive off and test that the chip still works. This is one of the reasons why it is good to have a fresh chip, you can have debug access to the chip and verify it works as intended.

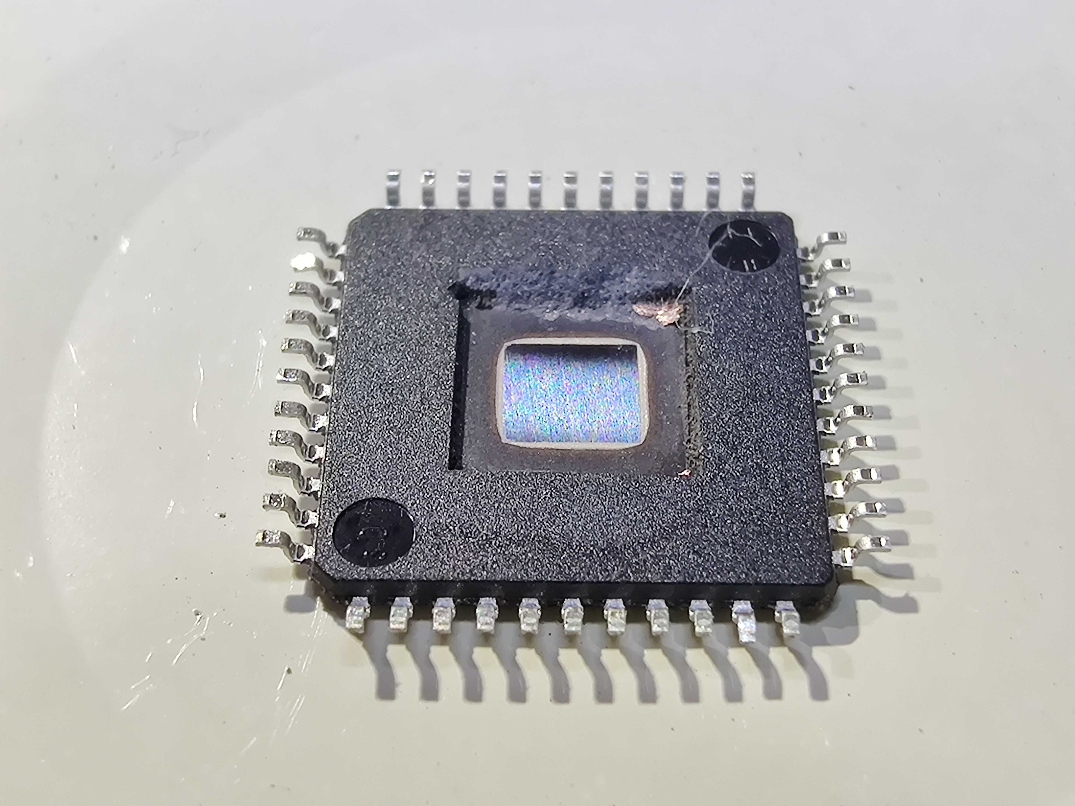
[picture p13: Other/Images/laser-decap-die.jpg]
Die cleaned with IPA


## Rinse and Repeat
If the chip worked as it should then it is time to rinse and repeat the same process for the actual chip you want to attack. Once you have the die visible you can start attacking it using LFI.

# Laser Settings

Provided that you are using the same Sculpfun 2W IR laser we introduced in our setup, here are some baseline settings we have found to be a good starting point for most chips. Note, as each setup is slightly different depending on the lens choices etc the parameters can vary quite a bit.

**Laser power:** 80% PWM duty

**Vertical Hop:** 5

**Horizontal Hop:** such that it takes around 3–5 seconds to do one pass

**Number of passes:** 3–6, has been most of the time enough to reveal die pad

**Dimensions:** depending on your chip but in our experiments your settings should be pretty good if you do one pass of 4mm x 4mm area in about 3–5 seconds.

The 2W IR laser is not powerful enough (at least without significant amount of passes) to cut the die pad even though it is very thin copper. So the best thing is to just try and eat the epoxy off around the die pad and then peel the die pad off.

# Conclusion

In this post, we explored the intricacies of chip decapping, from understanding the various packaging formats and materials used in epoxy-based packages, to examining the pros and cons of different decapping methods such as chemical, mechanical, and thermal approaches. We then introduced the revolutionary ability of our low-cost LFI rig to perform laser decapping using the same 2W IR laser used for glitching. This dual-functionality not only simplifies the decapping process but makes it faster and more efficient than traditional methods, allowing users to decap a chip and immediately proceed to glitching within minutes. With this versatile rig, we’re breaking new ground in hardware security testing, making advanced techniques accessible to a broader audience.

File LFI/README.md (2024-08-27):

# The Mechanics of Laser Fault Injection
LFI leverages the interaction between focused laser light and semiconductor materials to introduce faults in an IC’s operation. By precisely targeting the silicon die, an attacker can induce errors in the chip’s processing, leading to compromised security or system failures. The ability to control the timing and location of these faults is what makes LFI particularly potent.

# Beams and Spots
When a laser beam is focused onto the surface of an IC, its energy distribution follows a Gaussian curve. This characteristic of laser light is advantageous in LFI, as it allows for precise control over the laser’s impact area. The Gaussian profile means that the highest energy is concentrated at the center of the beam, with the intensity gradually decreasing toward the edges. When the laser hits the die surface from the backside, some of that energy is absorbed by the silicon layers.
Gaussian energy distribution of the laser beam spot

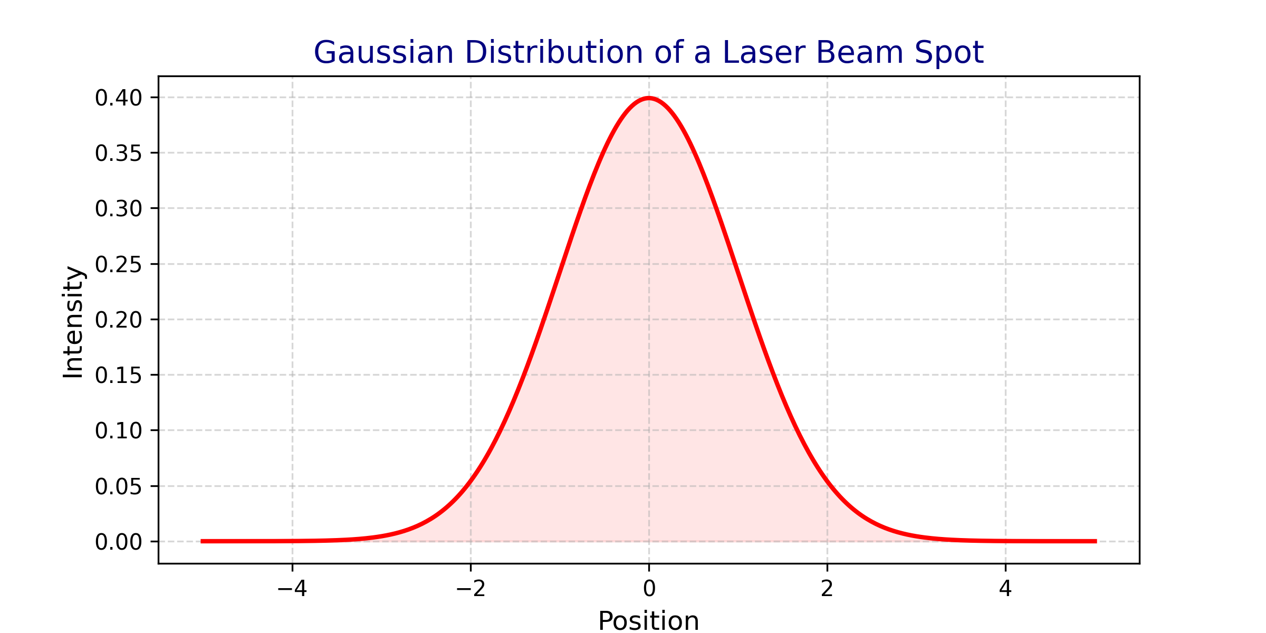
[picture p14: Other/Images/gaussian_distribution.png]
Laser beam spot distribution


This decay directly impacts the apparent spot size of the laser beam. While the physical spot size is defined by the diameter at which the beam’s intensity falls to a certain fraction of its maximum value (often 1/e² of the maximum intensity), the effective area impacted by the laser is larger due to the gradual falloff of energy. By carefully adjusting the laser’s power or pulse duration, we can reduce the apparent spot size on the other side of the die, effectively controlling the energy absorbed by the silicon.

Let’s consider a practical example. Suppose the minimum amount of energy required to penetrate the entire die through the backside is 0.15 (arbitrary units). This represents the smallest apparent spot size on the die, just enough to excite electrons in the transistor junction. Now, if we increase the pulse length or the power of the laser while maintaining the same spot size, we deliver more energy to the die, saturating a larger area. The dotted lines represent the width of the narrowest pulse we can achieve (red curve). As the pulse length increases or more power is applied, the affected area widens.

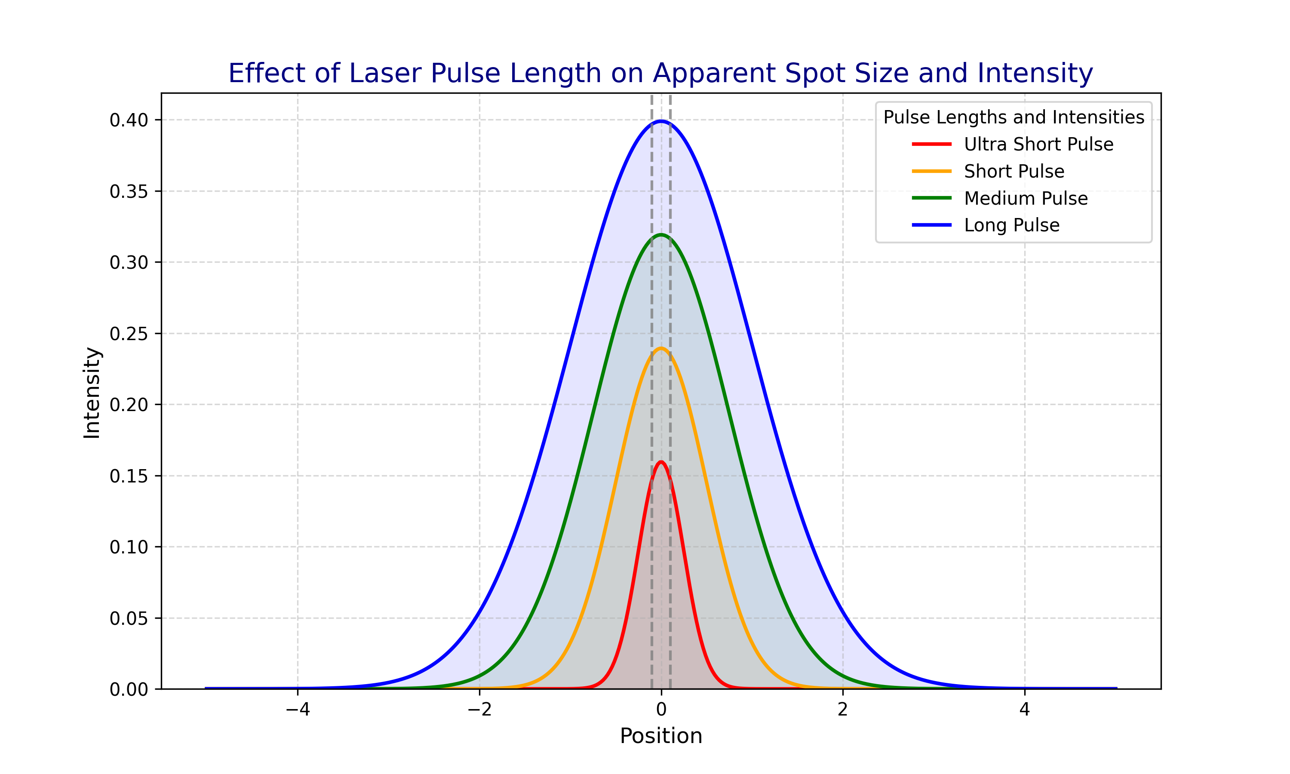
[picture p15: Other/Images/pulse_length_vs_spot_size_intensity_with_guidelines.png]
Effect of pulse length or power


In practical terms, if you want to flip single bits, you should optimize the power and pulse length to be just enough to penetrate the die. On the other hand, if your goal is to flip bits across a larger area, simply increase the power. Thus, rather than being a limitation, the natural falloff in energy becomes a tool for more precise and controlled fault injection.
How Laser Light Interacts with Semiconductor Materials

The effectiveness of LFI is rooted in the physical interactions between laser light and the semiconductor materials that make up an IC. The laser light can generate electron-hole pairs in the silicon substrate, leading to localized disruptions in the chip’s operation.

# Generation of Electron-Hole Pairs
When the laser beam strikes the silicon, its photons interact with the semiconductor material, generating electron-hole pairs through a process known as photoelectric excitation. The energy of the photons, in our case in the 1064nm infrared (IR) range, is sufficient to excite electrons from the valence band to the conduction band, creating free carriers that can move under the influence of an electric field.

This generation of electron-hole pairs is highly localized to the area where the laser is focused. The density of these pairs is greatest at the center of the laser spot, corresponding to the peak of the Gaussian intensity distribution of the beam. As these carriers are generated, they can cause transient changes in the voltages within the IC, leading to faults, or uncontrolled outputs.

The presence of these free carriers can significantly impact the operation of transistors within the IC. The additional carriers generated by the laser can either inject charge into the gate oxide or modulate the channel conductance, depending on the specific design and biasing of the transistor.

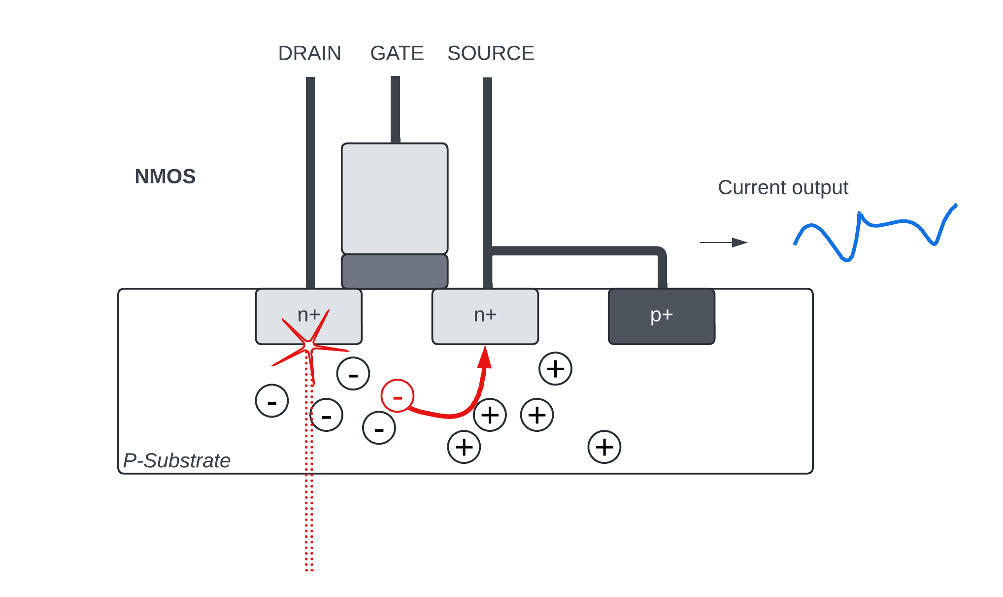
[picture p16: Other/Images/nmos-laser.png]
Laser hitting NMOS


For example, if the laser pulse targets the drain of an NMOS transistor in an off-state, the injected carriers can temporarily charge the drain region, effectively turning the transistor on for a brief period. This can cause a logic gate to output an incorrect value, which may propagate through the circuit and result in a fault.
Effect on Sense Amplifiers

Sense amplifiers, particularly those used in memory circuits, are among the most sensitive components to laser-induced faults. These amplifiers are designed to detect very small voltage differences and are, therefore, highly susceptible to the disruptions caused by laser-induced carriers.

When a laser pulse targets a sense amplifier, it can cause a temporary imbalance in the voltages being sensed, leading to incorrect amplification and data readout. For instance, in an SRAM cell, the laser could cause the sense amplifier to incorrectly interpret a stored ‘0’ as a ‘1’, resulting in a bit flip. This type of fault is particularly dangerous in secure systems, where data integrity is paramount.

# The Importance of Wavelength
When performing LFI through the backside of the IC, the wavelength of the laser plays a critical role in determining how effectively it can penetrate the silicon substrate and induce faults. The silicon substrate used in the IC manufacturing is “invisible” to light in the Infrared region. In technical terms, the absorption coefficient of the silicon substrate drastically drops as you approach a 1000nm wavelength. Consequently, wavelengths over 1000nm can penetrate the silicon substrate and reach the deeper layers where active components like transistors and sense amplifiers reside. This makes it possible to induce faults not just on the surface of the chip but deep within its structure, enabling attacks on buried circuitry.

# Expanding Possibilities with Moving Mirrors
One of the most significant advantages of our LFI rig is its use of fast-moving mirrors, which opens up a world of possibilities that were previously out of reach with traditional rigs where the sample itself needed to be physically moved. Our rig’s moving mirrors, allow for rapid and highly precise manipulation of the laser beam across the surface of the chip, enabling a variety of innovative fault injection patterns that can be tailored to specific attack scenarios.

With the flexibility of moving mirrors, we can now easily implement dynamic patterns such as sweeping a laser beam across an entire array of memory cells or flipping bits along a single line in one swift motion. This capability is particularly powerful when attacking large memory blocks or registers where inducing multiple faults in a single operation can lead to more significant disruptions. Moreover, the ability to create any arbitrary patterns over targeted areas allows us to flip bits in sequence or disrupt multiple regions simultaneously, enhancing the potential impact of the attack.

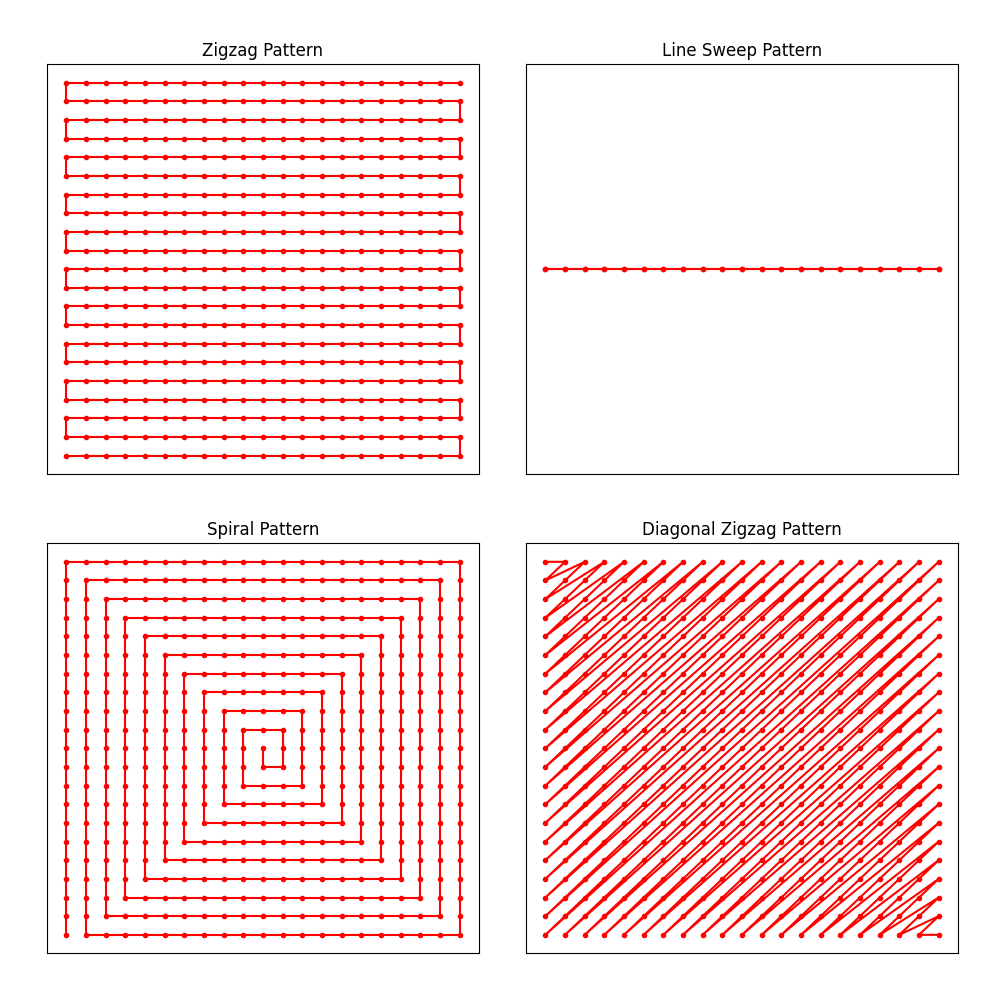
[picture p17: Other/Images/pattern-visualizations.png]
Beam patterns


This creative freedom extends far beyond the previous point and shoot to a single spot. For example, by programming the mirrors to follow a spiral pattern, we can gradually increase the area of influence, potentially causing cascading faults as the beam spirals outward from a central point. Alternatively, more intricate patterns could be designed to exploit specific vulnerabilities in an IC’s architecture, such as targeting the intersections of data buses or clock lines where faults could propagate and cause widespread system errors.

The possibilities are virtually limitless, and this is where the community’s involvement becomes crucial. While we’ve laid the groundwork with our rig, the true potential of these advanced patterns can only be fully realized through collective experimentation and shared insights. We encourage researchers and hobbyists alike to explore different patterns, directions and speeds, document their effects, and contribute to a growing body of knowledge on which patterns work best in various settings and with different types of ICs. Our GitHub repository also has a tool to visualize these patterns.

# Conclusion
In this post, we’ve explored the detailed mechanics of Laser Fault Injection, from the Gaussian beam of the laser spot to the complex interactions between laser light and semiconductor materials. We also discussed the entirely new ideas in executing LFI attacks using arbitrary targeting pattern.

As we continue to refine and explore the capabilities of our low-cost LFI rig, we’re eager to collaborate with the community. Whether you’re a researcher looking to expand on this work or someone new to the field, we invite you to join us in pushing the boundaries of what’s possible.

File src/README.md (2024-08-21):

# Source code files

## xy-driver.py
This is an example software driver for bitbanging the XY2-100 protocol using the Raspberry Pi Pico PIO

## pattern-visualizer.py
This is a helper script that can be used to plan and visualize the scan patterns for the galvanometer. The examples are the 4 most common patterns we have used, the zig-zag, line sweep, diagonal zig-zag and spiral.

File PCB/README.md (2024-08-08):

# XY2-100 driver board

This file contains remarks, notes and various things regarding the driver board and its assembly.

## Bill of materials

- **R1 & R2** - 1k Ohm 0603 resistor
- **R3** - 0 Ohm 0603 jumper
- **R4-R7** - 120 Ohm 0603 terminating resistors for the XY2-100 channels
- **J1** - Terminal Block, Metz Connect Type059 RT06303HBWC 1x3
- **J2 & J3** - Terminal Block, Metz Connect  Type059 RT06302HBWC 1x2
- **J4** - DB15 connector
- **PSU** - Traco Power TEN60-2423N, embedded power supply
- **U1** - Raspberry Pi Pico
- **U2** - LTC487CSW, 4 channel RS422/485 differential driver

## Remarks

- DB15 connector should be mounted on the opposite side of the PCB.
- Raspberry Pi Pico should be mounted on a pin header to allow for more cleareance under the USB cable

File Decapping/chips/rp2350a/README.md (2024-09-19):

# Rig settings

No need for laser on this one!

# Notes for die pad removal

The die pad is the same as the large ground pad on the bottom of the chip. Use a sharp thin knife and carefully press the knife into the area where the epoxy and ground pad meets. Work your way through a whole side and then use a sharpened flat head screwdriver to carefully peel the pad off. It should come off pretty easily. 

The bottom of the chip is pretty robust. There shouldn't be any issues for the chips functionality even if your knife slips a bit and cuts some of the epoxy. 

Shouldn't take more than few minutes to peel the pad off.

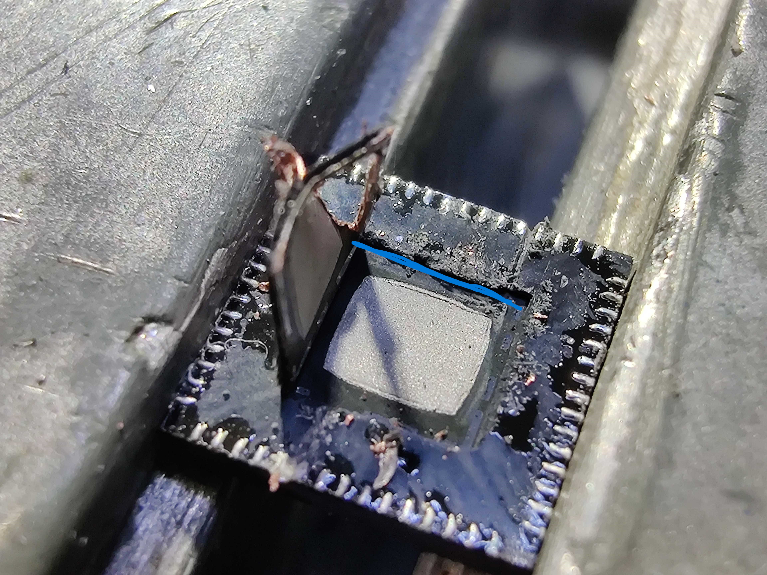
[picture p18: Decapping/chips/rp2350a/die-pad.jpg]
RP2350A


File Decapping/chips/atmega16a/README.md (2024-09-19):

# Rig settings

- Power: 80% duty
- Vertical hop: 5
- Horizontal hop: 20
- Dimensions: 4.5mm x 4.5mm 
- Passes: 6 passes to get to the die pad, some of the attempts have required one extra pass to get die pad cleanly visible

# Notes for die pad removal

Cut at least two of the corners of the die pad by pressing them with an edge of sharp knife. Do not apply a lot of force, the copper is very thin. Use an edge of a knife or a sharpened flat head screw driver to carefully peel the die pad up from the middle. Work one edge entirely and then bend the die pad off. Should be fairly easy to do without a lot of pressure.

If the die pad doesn't lift off, make one more pass with the laser.

There is plenty of material on the underside of the chip so even if you are a bit careless with the laser you should have any issues hitting anything critical like the bond wires.

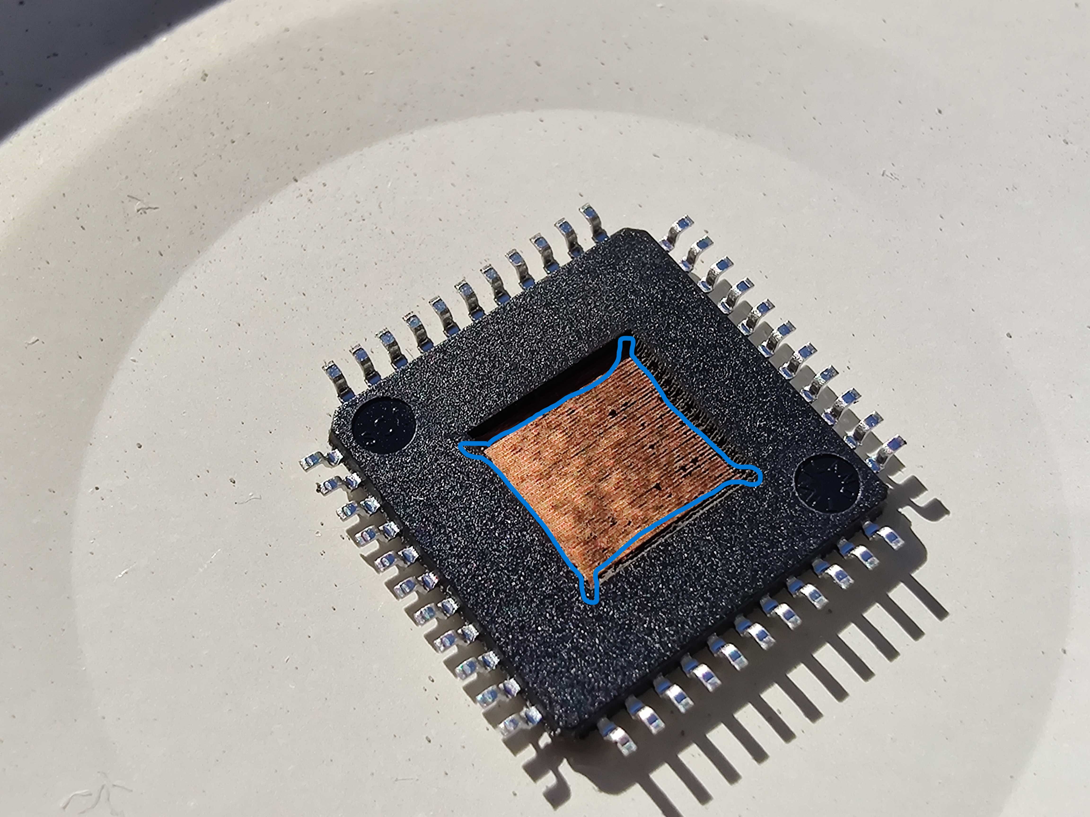
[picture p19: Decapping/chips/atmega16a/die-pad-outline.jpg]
ATmega16A


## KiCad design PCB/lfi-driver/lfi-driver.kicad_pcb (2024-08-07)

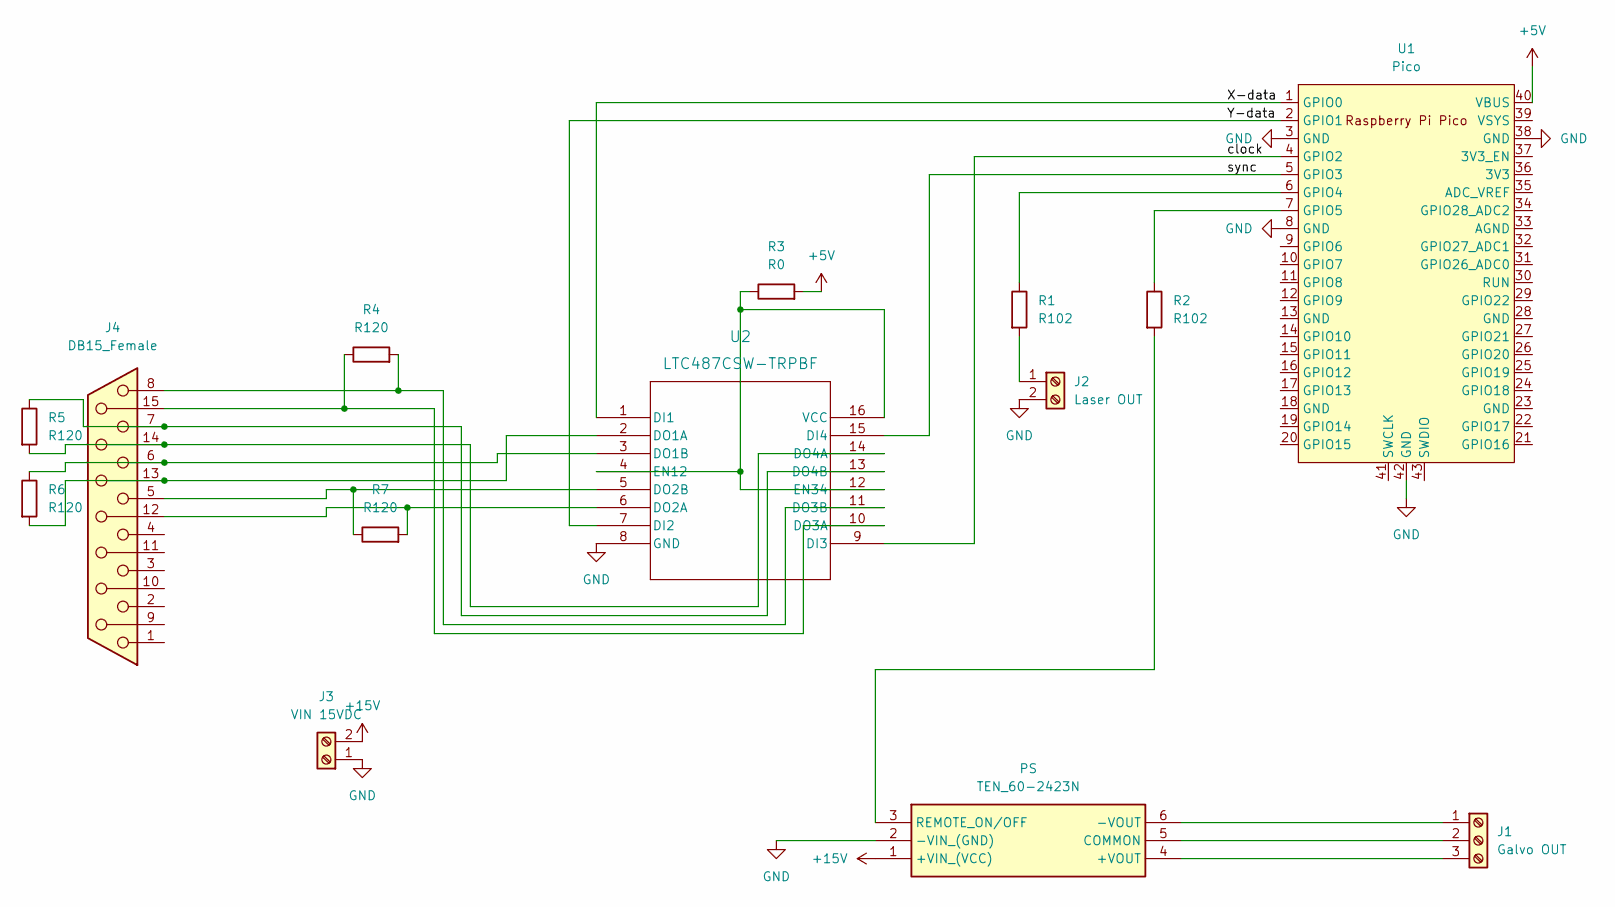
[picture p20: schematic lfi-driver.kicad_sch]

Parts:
J1: Galvo OUT; TerminalBlock_MetzConnect_Type059_RT06303HBWC_1x03_P3.50mm_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
J2: Laser OUT; TerminalBlock_MetzConnect_Type059_RT06302HBWC_1x02_P3.50mm_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
J3: VIN 15VDC; TerminalBlock_MetzConnect_Type059_RT06302HBWC_1x02_P3.50mm_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
J4: DB15_Female; DSUB-15_Female_Vertical_P2.77x2.84mm
PSU1: TEN_60-2423N; TEN602423N; Manufacturer_Part_Number TEN 60-2423N
R1, R2: R102; R_0603_1608Metric_Pad0.98x0.95mm_HandSolder
R3: R0; R_0603_1608Metric_Pad0.98x0.95mm_HandSolder
R4, R5, R6, R7: R120; R_0603_1608Metric_Pad0.98x0.95mm_HandSolder
U1: Pico; RPi_Pico_SMD_TH
U2: LTC487CSW-TRPBF; SO-16_SW_LIT

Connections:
+5V: R3.2, U1.40 (VBUS)
+15V: J3.2, PSU1.1 (+VIN_(VCC)); also elsewhere on the board
/X-data: U1.1 (GPIO0), U2.1 (DI1)
/Y-data: U1.2 (GPIO1), U2.7 (DI2)
/clock: U1.4 (GPIO2), U2.9 (DI3)
/sync: U1.5 (GPIO3), U2.15 (DI4)
GND: J2.2, J3.1, PSU1.2 (-VIN_(GND)), U1.3 (GND), U1.8 (GND), U1.38 (GND), U1.42 (GND), U2.8 (GND); also elsewhere on the board
unnamed 7: J1.1, PSU1.6 (-VOUT); also elsewhere on the board
unnamed 8: J1.2, PSU1.5 (COMMON); also elsewhere on the board
unnamed 9: J1.3, PSU1.4 (+VOUT); also elsewhere on the board
unnamed: J2.1, R1.2
unnamed 11: PSU1.3 (REMOTE_ON/OFF), R2.2; also elsewhere on the board
unnamed: R1.1, U1.6 (GPIO4)
unnamed: R2.1, U1.7 (GPIO5)
unnamed: R3.1, U2.4 (EN12), U2.12 (EN34), U2.16 (VCC)
unnamed: J4.15, R4.1, U2.10 (DO3A)
unnamed: J4.8, R4.2, U2.11 (DO3B)
unnamed: J4.5, R7.1, U2.5 (DO2B)
unnamed: J4.12, R7.2, U2.6 (DO2A)
unnamed: J4.13, R6.2, U2.2 (DO1A)
unnamed: J4.6, R6.1, U2.3 (DO1B)
unnamed: J4.7, R5.1, U2.13 (DO4B)
unnamed: J4.14, R5.2, U2.14 (DO4A)

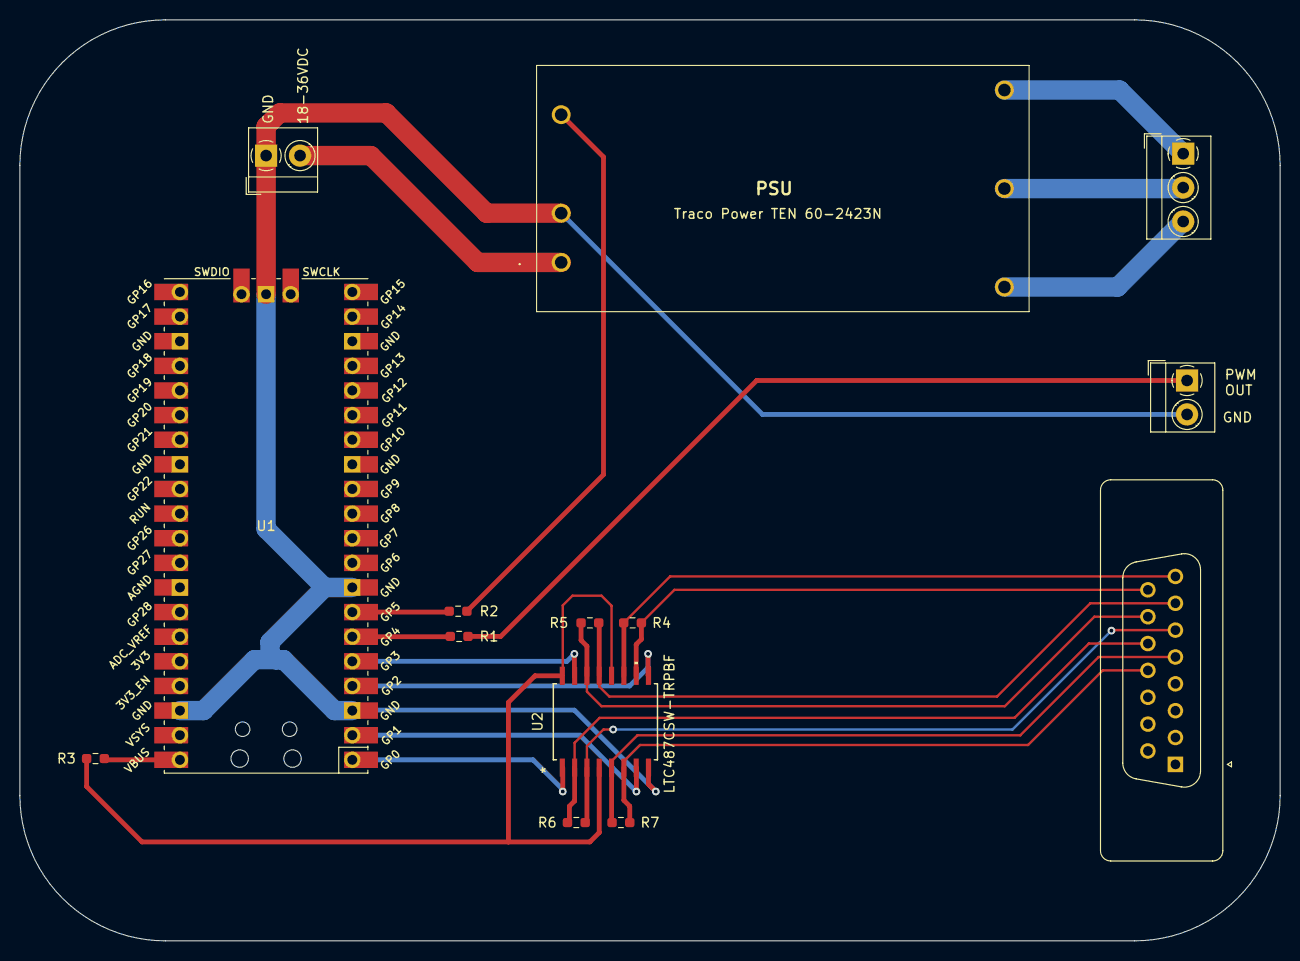
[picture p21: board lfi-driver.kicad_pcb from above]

Board: 2 copper layers, 130.0 x 95.0 mm, 14 parts (0 on the bottom side), 23 nets.

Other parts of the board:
PSU: TEN_60-2423N; TEN602423N

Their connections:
+15V: PSU.1 (+VIN_(VCC)); also elsewhere on the board
GND: PSU.2 (-VIN_(GND)); also elsewhere on the board
unnamed 7: PSU.6 (-VOUT); also elsewhere on the board
unnamed 8: PSU.5 (COMMON); also elsewhere on the board
unnamed 9: PSU.4 (+VOUT); also elsewhere on the board
unnamed 11: PSU.3 (REMOTE_ON/OFF); also elsewhere on the board

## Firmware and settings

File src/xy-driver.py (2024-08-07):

from machine import Pin, PWM
from rp2 import PIO, StateMachine, asm_pio
import time
import array
import random

#---------------------------
#Configuration parameters

#How much to sleep between mirror movements
SLEEPTIME = 0

#Value from 0 to 65535, for Sculpfun IR-2 values around 8000 start to produce faults on most ICs
LASERPOWER = 8000 



#---------------------------
#Setup parameters

laser = PWM(Pin(4))
laser.freq(1000) #1khz drive signal when using Sculpfun IR-2 laser
laser.duty_u16(0) #disable laser initially

#PSU Control
psu = Pin(5, Pin.OUT)
psu.low() #disable PSU initially


#Interleave bits using Z Curve a1 b1 a2 b2...
def interleaveBits(a, b):
    result = 0
    for i in range(32):  # Loop through each bit position
        # Mask and shift the bit from 'a' into the correct position in 'result'
        a_bit = (a >> i) & 1
        result |= a_bit << (2 * i)
        
        # Mask and shift the bit from 'b' into the correct position in 'result'
        b_bit = (b >> i) & 1
        result |= b_bit << (2 * i + 1)
    
    return result

#Calculate parity bit for XY2-100
def parity(int_type):
    parity = 0
    while (int_type):
        parity = ~parity
        int_type = int_type & (int_type - 1)
    return parity

#Make the actual XY2-100 dataframe
def makeFrame(val):
    global cmdCount
    frame = 0b1 << 16
    frame = frame | val
    if parity(frame) == 0:
        frame = frame << 1 | 1
    else:
        frame = frame << 1
    return int(frame)


#Hacky PIO Bitbanging implementation of XY2-100 protocol
@rp2.asm_pio(sideset_init=(rp2.PIO.OUT_LOW, rp2.PIO.OUT_LOW), out_init=(rp2.PIO.OUT_LOW, rp2.PIO.OUT_LOW), set_init=rp2.PIO.OUT_LOW, out_shiftdir=PIO.SHIFT_LEFT)
def XYWrite(): 
    pull()
    out(y,24)
    set(x,3)                 .side(0b00)
    label("hiloop")
    out(pins, 2)             .side(0b11)    [3]
    jmp(x_dec, "hiloop")     .side(0b10)	[3]
    pull()
    set(x,14)
    label("loloop")
    out(pins, 2)             .side(0b11)    [3]
    jmp(x_dec, "loloop")     .side(0b10)    [3]
    out(pins, 2)			 .side(0b01)	[3]
    nop()					 .side(0b00)	[3]

#Main function that controls the XY2-100 for mirror position this should be called when mirrors need to be moved
def drive(x,y):
    sm = rp2.StateMachine(0, XYWrite, freq=8*2000000, sideset_base=Pin(2), out_base=Pin(0))
    sm.active(1)
    xFrame = makeFrame(x)
    yFrame = makeFrame(y)
    
    #Make frames for x and y positions and interleave them using Z Curve x1 y1 x2 y2...
    #Turn the resulting 64bit xyFrame and split it into two 32bit words to send to PIO
    xyFrame = interleaveBits(xFrame,yFrame)
    a = array.array('I', [int((xyFrame>> 32) & 0xFFFFFFFF), int(xyFrame & 0xFFFFFFFF)])
    sm.put(a)
    time.sleep(SLEEPTIME)


#Helper function if using Sculpfun IR-2 module. This will move the mirrors very fast to make the adjusting beam
#to form a square that shows the scan area. Use this to adjust the xs,ys (x-start, y-start) and xe,ye (x-end, y-end)
#to be correct for the die you are working with
def findPerimeter(xs,xe,ys,ye,slp):
    psu.high()
    time.sleep(1)
    print("FIND PERIMETER MODE")
    while True:
        drive(xs,ys)
        time.sleep(slp)
        drive(xs,ye)
        time.sleep(slp)
        drive(xe,ye)
        time.sleep(slp)
        drive(xe,ys)
        time.sleep(slp)
    psu.low()


#This is the main function that is used with the REAL LASER!
#MAKE SURE YOU ARE WEARING LASER GOGGLES WHEN USING THIS!
#Parameters:
#xs,xe define the start and end for X-axis
#ys,ye define the start and end for Y-axis
#hop defines how much the mirror moves at a time
#shoot True/False defines if the laser is turned on/off
def scanChip(xs,xe,ys,ye, hop, shoot=False):
    psu.high()
    time.sleep(0.3) #This is an extra delay to compensate IR-2 startup time
    if shoot:
        laser.duty_u16(LASERPOWER)
    for y in range(ys, ye, hop):
        if(y == 0):
            start = time.ticks_ms()
        for x in range(xs, xe, hop):
            drive(x, y)
        if(y == 0):    
            end = time.ticks_ms()
            d = (((end-start)/1000)*(ye-y/hop))
            if shoot:
                print("SHOOT MODE ENABLED! Cover your EYES!")
                print("Laser power is", (LASERPOWER/65535)*100)
            print("One line in (s)", (end-start)/1000)
            print("Estimated completion (min) (hour):", d/60, d/60/60)
        if(y % 100 == 0):
            print("Completion (%):", (y/ye)*100)
    laser.duty_u16(0)
    psu.low()


#EXAMPLES HOW TO USE THE FUNCTIONS

print("WAITING FOR 5s, time to CANCEL")
time.sleep(5)


#Perform 300 iterations of whole chip scan with various hop-sizes to see how precise you need to be
#for i in range(0,300):
#    scanChip(0,3500,0,3500,random.randint(50,100),True)

#Example of using perimeter finding mode
#findPerimeter(2500,3500,0,3500,0)

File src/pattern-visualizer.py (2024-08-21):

# Helper script to visualize various scan patterns for the LFI right
# This script will make it easier to plan the scan before actually trying it out on a chip


import matplotlib.pyplot as plt

def zigzag_pattern(x_min, x_max, y_min, y_max, hop):
    direction = 1
    for y in range(y_min, y_max + 1, hop):
        if direction == 1:
            for x in range(x_min, x_max + 1, hop):
                yield (x, y)
        else:
            for x in range(x_max, x_min - 1, -hop):
                yield (x, y)
        direction *= -1

def line_sweep(x_min, x_max, y_min, y_max,  hop):
    # Sweep from left to right
    for x in range(x_min, x_max + 1, hop):
        yield (x, y_min)
    # Sweep from right to left
    for x in range(x_max, x_min - 1, -hop):
        yield (x, y_min)


def spiral_pattern(x_min, x_max, y_min, y_max, step):
    # Calculate center and starting conditions
    x_center, y_center = (x_max + x_min) // 2, (y_max + y_min) // 2
    x, y = x_center, y_center
    dx, dy = 0, -step
    segment_length = step
    segment_passed = 0
    
    # Adjustments to ensure the spiral expands
    while x_min <= x <= x_max and y_min <= y <= y_max:
        yield (x, y)
        # Check if we need to turn
        if segment_passed == segment_length:
            # Turn counter-clockwise
            dx, dy = -dy, dx
            segment_passed = 0
            # Every time we complete two turns, increase the segment length
            if dx == 0:
                segment_length += step
        
        # Move to the next point
        x += dx
        y += dy
        segment_passed += step


def diagonal_zigzag(x_min, x_max, y_min, y_max, hop):
    direction = 1
    for diag in range(0, (x_max - x_min) + (y_max - y_min) + 1, hop):
        x_start = max(x_min, x_max - diag)
        y_start = max(y_min, y_min + diag - (x_max - x_min))
        while x_start <= x_max and y_start <= y_max:
            yield (x_start, y_start)
            x_start += hop
            y_start += hop
        direction *= -1

def plot_pattern(generator, x_min, x_max, y_min, y_max, title, hop):
    x_vals, y_vals = zip(*list(generator(x_min, x_max, y_min, y_max, hop)))
    plt.figure()
    plt.plot(x_vals, y_vals, marker='o')
    plt.title(title)
    plt.xlim([x_min - 1, x_max + 1])
    plt.ylim([y_min - 1, y_max + 1])
    plt.grid(True)

# Define boundaries
x_min, x_max, y_min, y_max, hop = 0, 100, 0, 100, 10


def plot_patterns_together(x_min, x_max, y_min, y_max, step):
    # Create a figure and set of subplots
    fig, axs = plt.subplots(2, 2, figsize=(10, 10))  # Adjust the figure size as needed for clarity

    # Assign patterns to subplots
    patterns = [
        (zigzag_pattern, "Zigzag Pattern", axs[0, 0]),
        (line_sweep, "Line Sweep Pattern", axs[0, 1]),
        (spiral_pattern, "Spiral Pattern", axs[1, 0]),
        (diagonal_zigzag, "Diagonal Zigzag Pattern", axs[1, 1])
    ]

    for generator, title, ax in patterns:
        if title == "Line Sweep Pattern":
            y = (y_min + y_max) // 2  # fixed y-value for line sweep
            x_vals, y_vals = zip(*list(generator(x_min, x_max, y, 0, step)))
        else:
            x_vals, y_vals = zip(*list(generator(x_min, x_max, y_min, y_max, step)))
        
        ax.plot(x_vals, y_vals, marker='o', color='red', markersize=3)
        ax.set_title(title)
        ax.set_xlim([x_min - 1, x_max + 1])
        ax.set_ylim([y_min - 1, y_max + 1])
        ax.grid(False)  # Turn off the grid
        ax.set_xticks([])  # Remove x-axis ticks
        ax.set_yticks([])  # Remove y-axis ticks

    plt.tight_layout(pad=3.0)
    plt.suptitle('Laser Beam Movement Patterns', fontsize=16, color='black', y=1.02) 
    plt.show()

# Define boundaries
x_min, x_max, y_min, y_max, step = 0, 20, 0, 20, 1

# Call the plotting function
plot_patterns_together(x_min, x_max, y_min, y_max, step)
